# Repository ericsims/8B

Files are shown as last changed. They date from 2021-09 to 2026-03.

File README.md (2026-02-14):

# 8 Bit TTL Computer
a simple 8 bit CISC computer built using TTL logic

## SW DEV

### packages
`sudo apt-get install python3-tk ffmpeg`

### customasm
`curl --proto '=https' --tlsv1.3 https://sh.rustup.rs -sSf | sh`
`cargo install customasm`

### python setup

`python3 -m venv .venv`
`source .venv/bin/activate`
`python -m pip install pip-tools`
`pip-compile.exe requirements.in`
`pip install -r requirements.txt`

## CPLD DEV

### Quartus

Quartus II v13.0 sp1
https://www.intel.com/content/www/us/en/software-kit/711791/intel-quartus-ii-web-edition-design-software-version-13-0sp1-for-windows.html

### POF2JED

https://www.microchip.com/en-us/products/fpgas-and-plds/spld-cplds/pld-design-resources

### GHDL

in MSYS2 MSYS `pacman -S mingw64/mingw-w64-x86_64-ghdl-llvm`

### gtkwave

`https://github.com/gtkwave/gtkwave/releases`

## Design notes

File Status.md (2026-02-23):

# Backplane

DONE

# ALU Ctrl

DONE

# ALU Logic

DONE

# ALU Adder

DONE

# Memory Proto

DONE

# Registers

- [x] board keep out
- [x] silkscreen
- [x] part number/date
- [x] teardrops
- [x] polygons
- [x] run out jobs
- [x] quote
- [ ] order
- [ ] assemble

# Scratch

- [x] board keep out
- [x] silkscreen
- [x] part number/date
- [x] teardrops
- [x] polygons
- [x] run out jobs
- [x] quote
- [ ] order
- [ ] assemble

# Program Counter

- [x] board keep out
- [x] silkscreen
- [x] part number/date
- [x] teardrops
- [x] polygons
- [x] run out jobs
- [x] quote
- [ ] order
- [ ] assemble

# SRAM

- [x] board keep out
- [x] silkscreen
- [x] part number/date
- [x] teardrops
- [x] polygons
- [ ] run out jobs
- [ ] quote
- [ ] order
- [ ] assemble

# EEPROM

- [x] board keep out
- [x] silkscreen
- [x] part number/date
- [x] teardrops
- [x] polygons
- [ ] run out jobs
- [ ] quote
- [ ] order
- [ ] assemble

# Clock Proto

- [ ] board keep out
- [ ] silkscreen
- [ ] part number/date
- [ ] teardrops
- [ ] polygons
- [ ] run out jobs
- [ ] quote
- [ ] order
- [ ] assemble

# Memory Address Decoder

- [x] board keep out
- [x] silkscreen
- [x] part number/date
- [x] teardrops
- [x] polygons
- [ ] run out jobs
- [ ] quote
- [ ] order
- [ ] assemble

# Remaining Work
- Power Module - 8 hours
- Control Module - 24 hours
- Memory Address Register - 8 hours
- Memory Decoder - DONE, NEED QUOTE
- EEPROM - DONE, NEED QUOTE
- SD card - 8 hours
- Ethernet - 12 hours
- Graphics - 12 hours
- UART - 12 hours
- Extended RAM - 8 hours
- Keyboard - 12 hours
- SNES - 4 hours?

pcb assembly: 40 hours
total pcb design work: 160 hours

mechanical design: ~40?
mechanical assembly 12 hours?

total mech work: 52 hours

hardware debug effort???
control debugging: 80 hours

app dev
graphics demos: 40 hours
ethernet demos: 40 hours
weather app: 80 hours
snakey game: 80 hours?
total app dev: 240

display prep
16 hours

total: 556 hours

All PCBs/Hardware ordered by 3/7

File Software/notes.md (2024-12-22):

# instructions

consider adding a set of jump instructions that is relative to PC, rather than just an immediate address. This would allow for programs to be dynamically ran out of ram, or even the stack.

Need to finish test coverage of all the instructions and corner cases

# math

finish corner case testing of existing math functions

sine CORDIC needs more testing. I am not sure it is always converging correctly. Consider caching the sine/cosine outputs in the future if desired - or maybe just return both always?

sqrt and ln are broken due to some change in the offset addressing. consider ditching the LUT approach and just write a hyperbolic CORDIC implementation.

# file system

consider a FAT16 FS implementation on SD card. This would be simple on SPI bus. James has a video on it.

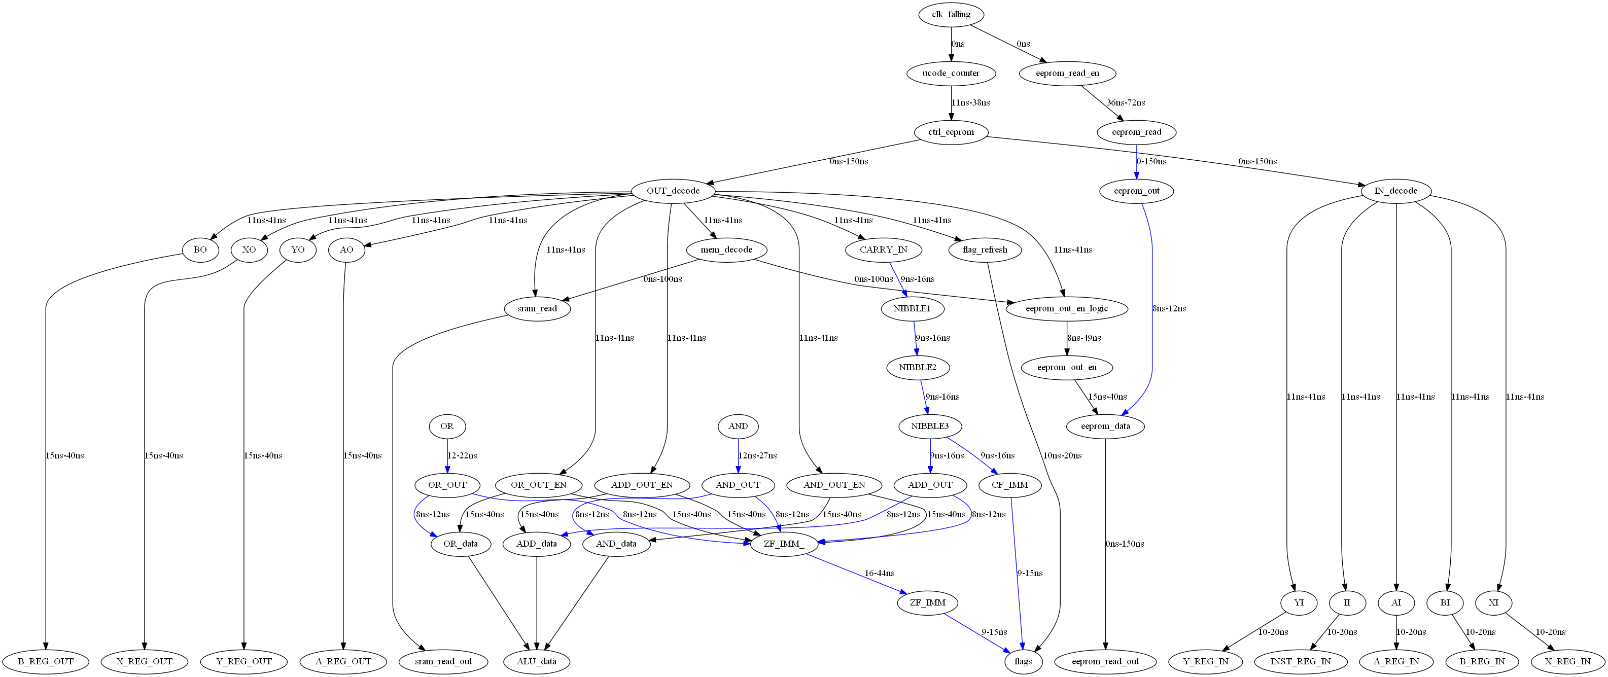
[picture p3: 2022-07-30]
Software/lib_dev/Timing/output.png

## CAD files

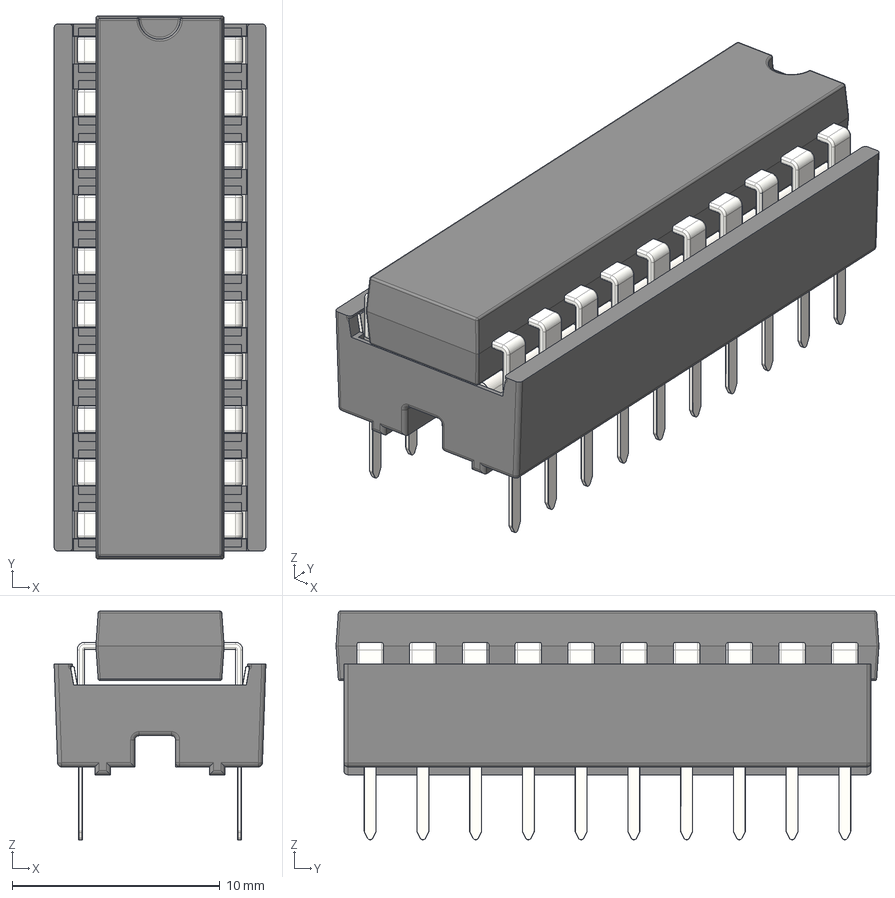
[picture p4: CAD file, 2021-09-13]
Hardware/ic-dip-packages-with-sockets-in-pitch-7-62mm-1.snapshot.2/DIP-20 W7.62mm IC with Socket.stp
10.2 x 26.1 x 11.0 mm
Stamped Dual Wipe Contact for DIP Sockets x 20
Body DIP-20 P7.62mm Socket
IC Beinchen x 20
DIP-20 W7.62

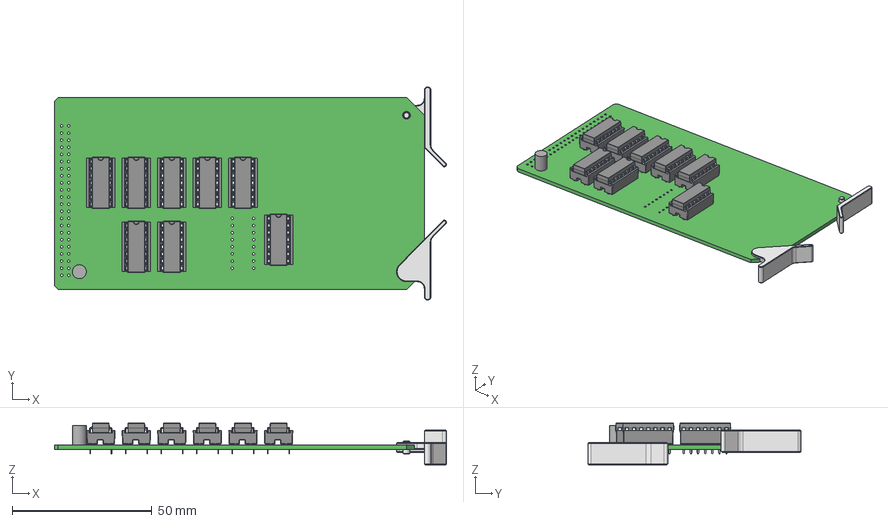
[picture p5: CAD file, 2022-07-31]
Hardware/Memory Address Decoder/Mechanical/Memory Address Decoder.step
140.0 x 76.2 x 14.9 mm
Stamped_Dual_Wipe_Contact_for_DIP_Sockets x 112
Body_DIP-14_P7.62mm_Socket x 8
IC_Beinchen x 112
DIP-14_W7.62 x 8
Ejector x 2

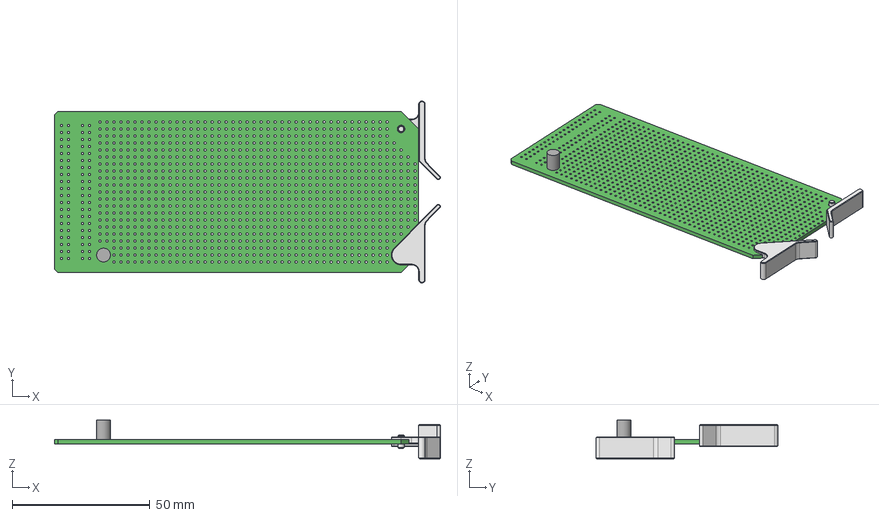
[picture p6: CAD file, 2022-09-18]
Hardware/Memory_Proto/Mechanical/Memory_Proto.step
140.0 x 66.0 x 14.0 mm
Ejector x 2

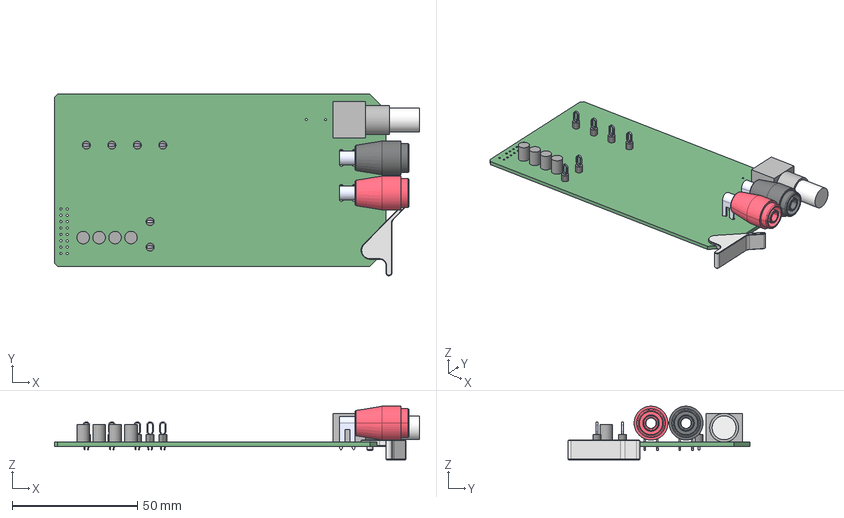
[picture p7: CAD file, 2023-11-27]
Hardware/Power_Clock_proto/Mechanical/Power_Clock_proto.step
145.4 x 72.4 x 21.4 mm
keystone-PN5011 x 6
Extruded
CT3151SP-0
CT3151SP-2
Ejector

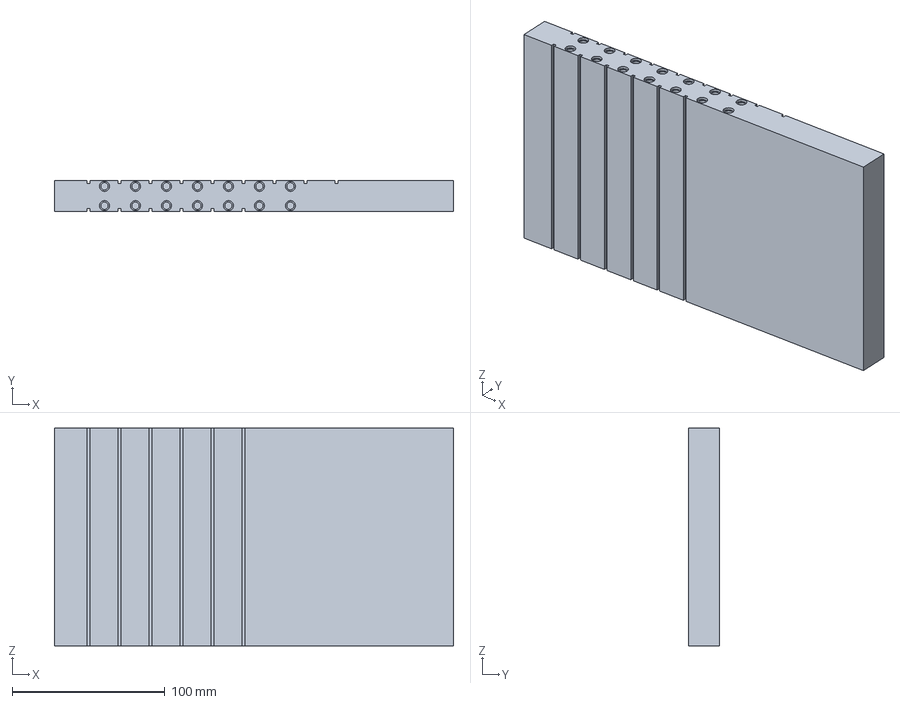
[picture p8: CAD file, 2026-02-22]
Mechanical/card_cage/mid_cage_b.FCStd
261.6 x 20.3 x 142.7 mm

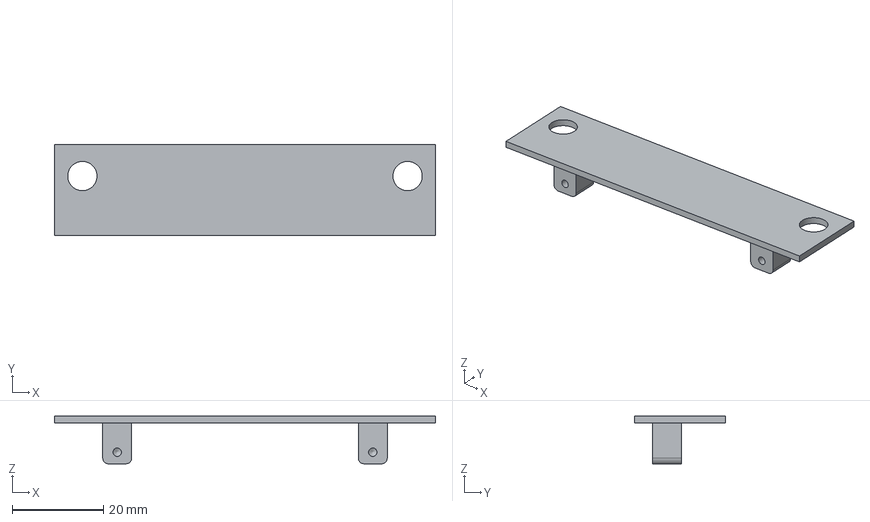
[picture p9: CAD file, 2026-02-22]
Mechanical/export/Reg_Cover_Plain.step
83.3 x 19.8 x 10.4 mm

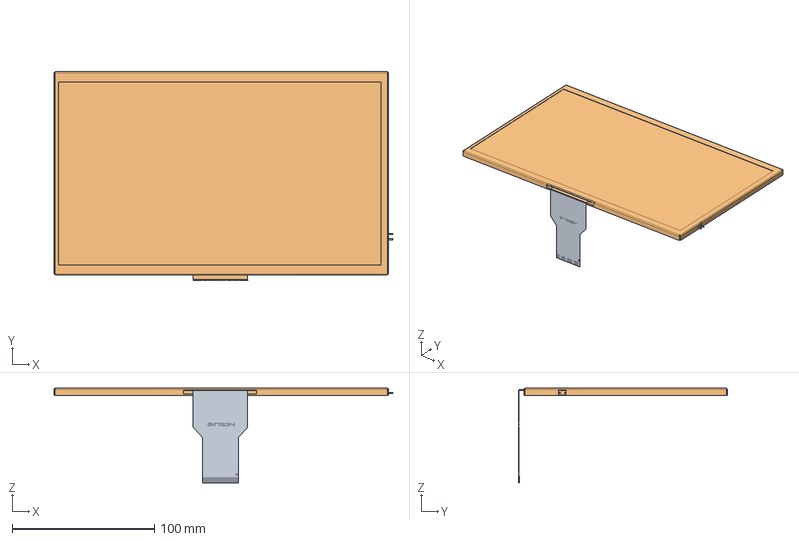
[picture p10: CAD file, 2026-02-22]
Mechanical/front/ER-TFT101-1_screen.FCStd
238.2 x 146.7 x 66.4 mm
Slice.002

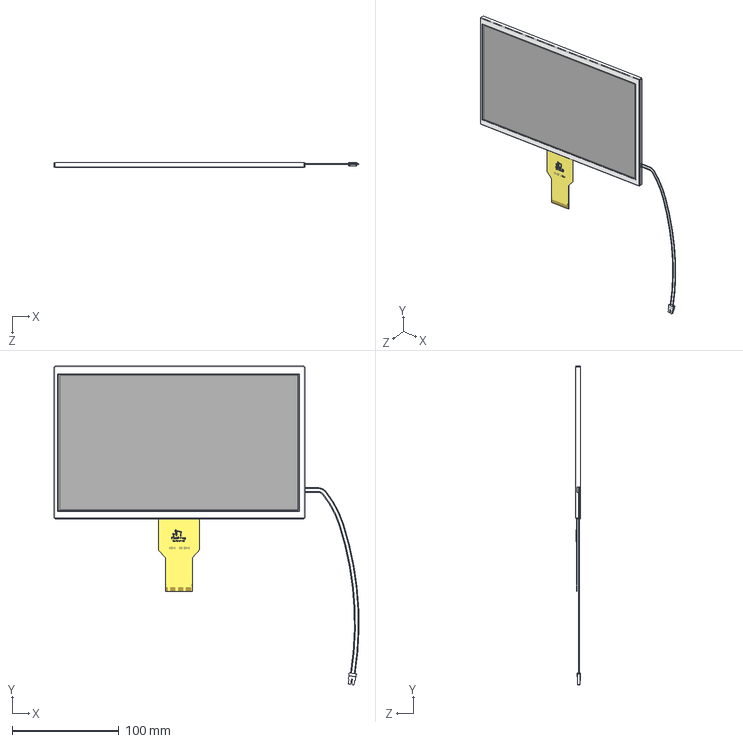
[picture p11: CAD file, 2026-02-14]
Mechanical/vendor_models/ER-TFT101B-4-1.STEP
285.5 x 298.5 x 5.00 mm
10.1 DISPLAY BEZEL
Backlight Connector

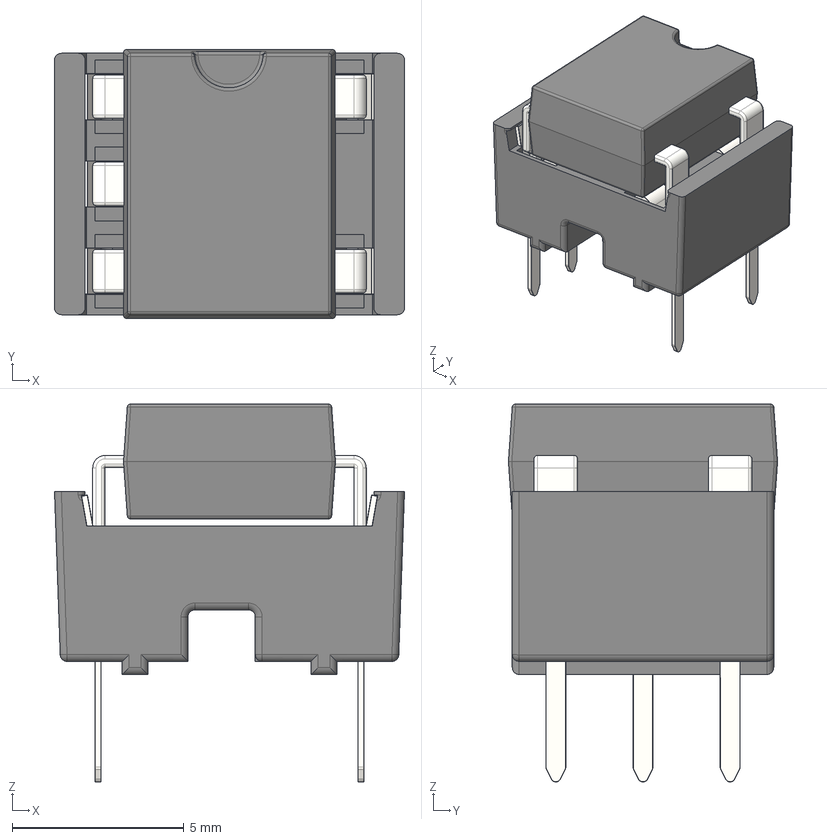
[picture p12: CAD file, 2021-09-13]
Hardware/ic-dip-packages-with-sockets-in-pitch-7-62mm-1.snapshot.2/DIP-5 W7.62mm IC with Socket.stp
10.2 x 7.85 x 11.0 mm
Stamped Dual Wipe Contact for DIP Sockets x 5
IC Beinchen x 5
DIP-5 W7.62
Body DIP-5 P7.62mm Socket

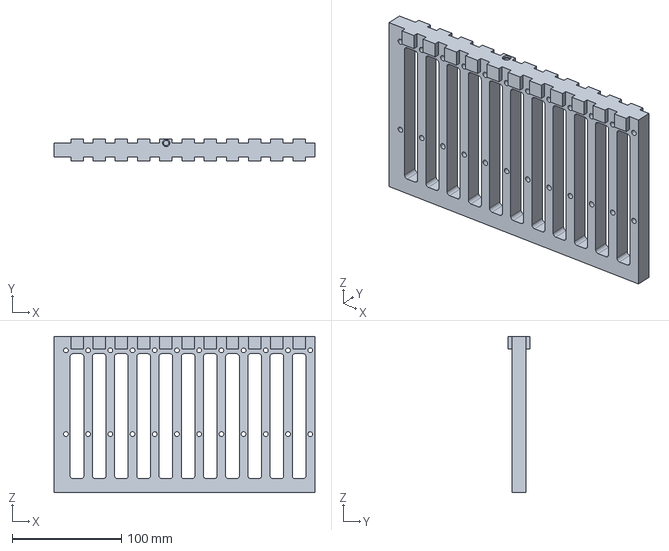
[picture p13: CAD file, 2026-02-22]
Mechanical/card_cage/mid_cage.FCStd
238.8 x 20.3 x 142.7 mm

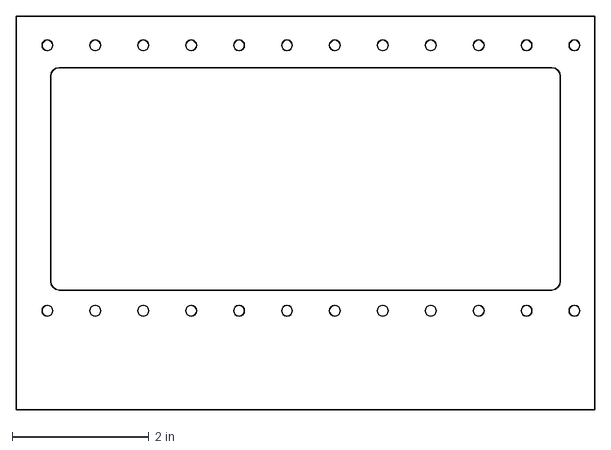
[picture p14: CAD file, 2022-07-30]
Mechanical/centerwall.dxf
8.45 x 5.75 in

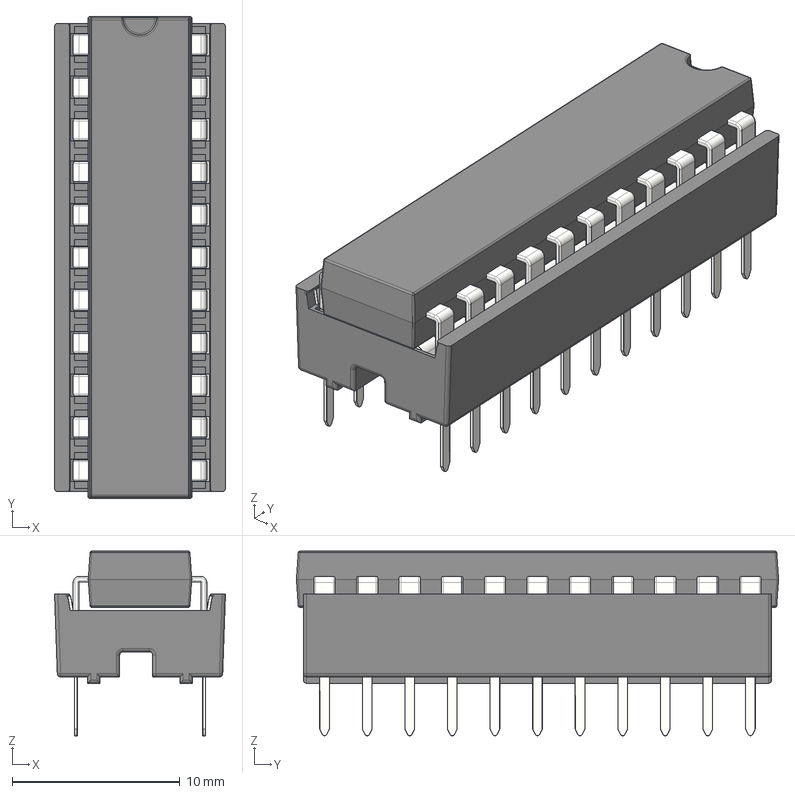
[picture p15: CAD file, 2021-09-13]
Hardware/ic-dip-packages-with-sockets-in-pitch-7-62mm-1.snapshot.2/DIP-22 W7.62mm IC with Socket.stp
10.2 x 28.8 x 11.0 mm
Stamped Dual Wipe Contact for DIP Sockets x 22
Body DIP-22 P7.62mm Socket
IC Beinchen x 22
DIP-22 W7.62

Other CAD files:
Mechanical/Assembly.FCStd
Mechanical/pcbs/ALU_Ctrl_Assembly.FCStd
Mechanical/front/Front Assembly.FCStd
Hardware/Backplane/Mechanical/Backplane.step
Mechanical/pcbs/Reg_Cover_Blank.FCStd
Mechanical/card_cage/card_cage.FCStd
Hardware/ALU_Add_Shift/Mechanical/6403217136.iam
Hardware/ALU_Add_Shift/Mechanical/6403219456.iam
Hardware/ALU_Add_Shift/Mechanical/6403219696.iam
Hardware/ALU_Add_Shift/Mechanical/6517111024.iam
Hardware/ALU_Add_Shift/Mechanical/ALU_Add_Shift.iam
Hardware/ALU_Add_Shift/Mechanical/Board.iam
Hardware/ALU_Add_Shift/Mechanical/Body_DIP-14_P7.62mm_Socket.ipt
Hardware/ALU_Add_Shift/Mechanical/Body_DIP-16_P7.62mm_Socket.ipt
Hardware/ALU_Add_Shift/Mechanical/Body_DIP-20_P7.62mm_Socket.ipt
Hardware/ALU_Add_Shift/Mechanical/C1.iam
Hardware/ALU_Add_Shift/Mechanical/C13.iam
Hardware/ALU_Add_Shift/Mechanical/C14.iam
Hardware/ALU_Add_Shift/Mechanical/C15.iam
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

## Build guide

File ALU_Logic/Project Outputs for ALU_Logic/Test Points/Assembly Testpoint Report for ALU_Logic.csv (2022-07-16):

Net | Name | X Coord | Y Coord | Side | Hole Size | Type
M\10 | TP8-1 | 4900mil | 2700mil | Top | 62.992mil | Through hole
M\9 | TP7-1 | 4400mil | 2700mil | Top | 62.992mil | Through hole
M\8 | TP6-1 | 5400mil | 2700mil | Top | 62.992mil | Through hole
M\5 | TP5-1 | 3600mil | 1500mil | Top | 62.992mil | Through hole
M\4 | TP4-1 | 2600mil | 1500mil | Top | 62.992mil | Through hole
AND_OUT# | TP3-1 | 1600mil | 1500mil | Top | 62.992mil | Through hole
VCC | TP2-1 | 2100mil | 1200mil | Top | 62.992mil | Through hole
GND | TP1-1 | 2400mil | 1200mil | Top | 62.992mil | Through hole

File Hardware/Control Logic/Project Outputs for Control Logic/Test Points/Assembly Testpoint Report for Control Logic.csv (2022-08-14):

Net | Name | X Coord | Y Coord | Side | Hole Size | Type
GND | TP11-1 | 11000mil | 1200mil | Top | 62.992mil | Through hole
GND | TP12-1 | 10700mil | 1200mil | Top | 62.992mil | Through hole
VCC | TP14-1 | 10100mil | 1200mil | Top | 62.992mil | Through hole
GND | TP13-1 | 10400mil | 1200mil | Top | 62.992mil | Through hole
GND | TP9-1 | 11600mil | 1200mil | Top | 62.992mil | Through hole
GND | TP10-1 | 11300mil | 1200mil | Top | 62.992mil | Through hole
GND | TP8-1 | 11900mil | 1200mil | Top | 62.992mil | Through hole
DBG | TP7-1 | 12200mil | 1200mil | Top | 62.992mil | Through hole
AT# | TP6-1 | 12500mil | 1200mil | Top | 62.992mil | Through hole
HT# | TP5-1 | 12800mil | 1200mil | Top | 62.992mil | Through hole
RST# | TP4-1 | 13100mil | 1200mil | Top | 62.992mil | Through hole
LM# | TP3-1 | 13400mil | 1200mil | Top | 62.992mil | Through hole
RU# | TP1-1 | 3600mil | 7700mil | Bottom | 62.992mil | Through hole
CLK | TP2-1 | 3400mil | 8100mil | Bottom | 62.992mil | Through hole

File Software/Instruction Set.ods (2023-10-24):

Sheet: Sheet1_2
LAI | Load A Immediate | 0x02 | LAI, VAL
0 | FETCH
1 | FETCH
2 | FETCH
3 | MC, CE
4 | MO, AI, RU
LBI | Load B Immediate | 0x03 | LBI, VAL
0 | FETCH
1 | FETCH
2 | FETCH
3 | MC, CE
4 | MO, BI, RU
ADD | A + B → A | 0x04 | ADD
0 | FETCH
1 | FETCH
2 | FETCH
3 | Mn=1, AI, RU, FI
SUB | A + B → A | 0x06 | SUB
0 | FETCH
1 | FETCH
2 | FETCH
3 | Mn=2, AI, RU, FI
JMZ | Jump if zero | 0x07 | JMZ, MSB, LSB
0 | FETCH
1 | FETCH
2 | FETCH
3 | if(ZF, [MC], [CE])
4 | if(ZF, [PI, LN=1 ,MO], [CE, RU])
5 | if(ZF, [MC], [])
6 | if(ZF, [PI, Ln=0, MO, RU], [])
JNZ | Jump if not zero | 0x08 | JNZ, MSB, LSB
0 | FETCH
1 | FETCH
2 | FETCH
3 | if(ZF, [CE], [MC])
4 | if(ZF, [CE, RU], [PI, LN=1 ,MO])
5 | if(ZF, [], [MC])
6 | if(ZF, [], [PI, Ln=0, MO, RU])
STA | Store A to memory | 0x09 | STA, MSB, LSB
0 | FETCH
1 | FETCH
2 | FETCH
3 | MC, CE
4 | MO, PH
5 | MC, CE
6 | MO, PH
7 | PP, MA, Ln=0
8 | PP, MA, Ln=1
9 | AO, MI, RU
LBA | A → B | 0x0A | LBA
0 | FETCH
1 | FETCH
2 | FETCH
3 | BI, AO, RU
LDA | load memory to A | 0x0B | LDA, MSB, LSB
0 | FETCH
1 | FETCH
2 | FETCH
3 | MC , CE
4 | MO, PH
5 | MC, CE
6 | MO, PH
7 | PP, MA, Ln=0
8 | PP, MA, Ln=1
9 | AI, MO, RU
LDB | load memory to B | 0x0C | LDB, MSB, LSB
0 | FETCH
1 | FETCH
2 | FETCH
3 | MC , CE
4 | MO, PH
5 | MC, CE
6 | MO, PH
7 | PP, MA, Ln=0
8 | PP, MA, Ln=1
9 | BI, MO, RU
JMC | Jump if carry | 0x0D | JMC, MSB, LSB
0 | FETCH
1 | FETCH
2 | FETCH
3 | if(CF, [MC], [CE])
4 | if(CF, [PI, LN=1 ,MO], [CE, RU])
5 | if(CF, [MC], [])
6 | if(CF, [PI, Ln=0, MO, RU], [])
JNC | Jump if not carry | 0x0E | JNC, MSB, LSB
0 | FETCH
1 | FETCH
2 | FETCH
3 | if(CF, [CE], [MC])
4 | if(CF, [CE, RU], [PI, LN=1 ,MO])
5 | if(CF, [], [MC])
6 | if(CF, [], [PI, Ln=0, MO, RU])
STI | Store Immediate to memory | 0x0F | STI, VAL, MSB, LSB
0 | FETCH
1 | FETCH
2 | FETCH
3 | MC , CE
4 | MO, PH
5 | MC, CE
6 | MO, PH
7 | MC, CE
8 | MO, PH
9 | PP, MA, Ln=0
10 | PP, MA, Ln=1
11 | PP, MI, RU
CAL | Call subroutine | 0X10 | CAL, MSB, LSB
0 | FETCH
1 | FETCH
2 | FETCH
3 | CE
4 | CE
5 | PH, PO, Ln=1
6 | PH, PO, Ln=0, MC
7 | PI, LN=1 ,MO
8 | MC, CE
9 | PI, Ln=0, MO, RU
RET | Return from subroutine | 0x11 | RET
0 | FETCH
1 | FETCH
2 | FETCH
3 | PP, MA, Ln=0
4 | PP, MA, Ln=1, RU
JMN | Jump if negative | 0x12 | JMN, MSB, LSB
0 | FETCH
1 | FETCH
2 | FETCH
3 | if(NF, [MC], [CE])
4 | if(NF, [PI, LN=1 ,MO], [CE, RU])
5 | if(NF, [MC], [])
6 | if(NF, [PI, Ln=0, MO, RU], [])
RLC | shift left | 0x13 | RLC
0 | FETCH
1 | FETCH
2 | FETCH
3 | Mn=6, AI, RU, FI
RRC | right shift | 0x14 | RLC
0 | FETCH
1 | FETCH
2 | FETCH
3 | Mn=7, AI, RU, FI
PHA | push a to stack | 0x15 | PHA
0 | FETCH
1 | FETCH
2 | FETCH
3 | AO, PH, RU
SSA | Store A to MI at address on stack | 0x17 | SSA
0 | FETCH
1 | FETCH
2 | FETCH
3 | PP, MA, Ln=1
4 | PP, MA, Ln=0
5 | MI, AO, RU
LSA | Load memory at address in stack to A | 0x18 | LSA
0 | FETCH
1 | FETCH
2 | FETCH
3 | PP, MA, Ln=1
4 | PP, MA, Ln=0
5 | MO, AI, RU
TTA | Test instruction. Asserts that A reg equals operand | 0xFE | TTA, VAL
0 | FETCH
1 | FETCH
2 | FETCH
4 | MC, CE
5 | RU, (sim to check that A == operand)
TTZ | Test instruction. Asserts that ZF reg equals operand | 0xFD | TTZ, VAL
0 | FETCH
1 | FETCH
2 | FETCH
4 | MC, CE
5 | RU, (sim to check that ZF == operand)
TTC | Test instruction. Asserts that CF equals operand | 0xFC | TTC, VAL
0 | FETCH
1 | FETCH
2 | FETCH
4 | MC, CE
5 | RU, (sim to check that CF == operand)
TTN | Test instruction. Asserts that NF equals operand | 0xFB | TTN, VAL
0 | FETCH
1 | FETCH
2 | FETCH
4 | MC, CE
5 | RU, (sim to check that NF == operand)
AND | A & B → A | 0x19 | AND
0 | FETCH
1 | FETCH
2 | FETCH
3 | Mn=3, AI, RU, FI
OOR | A | B → A | 0x20 | OOR
0 | FETCH
1 | FETCH
2 | FETCH
3 | Mn=4, AI, RU, FI
XOR | A XOR B → A | 0x21 | XOR
0 | FETCH
1 | FETCH
2 | FETCH
3 | Mn=5, AI, RU, FI

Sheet: Sheet1
LAI | Load A Immediate | 0x02 | LAI, VAL
0 | FETCH
1 | FETCH
2 | FETCH
3 | MC, CE
4 | MO, AI, RU
HLT |  | 0xFF | HLT
0 | FETCH
1 | FETCH
2 | FETCH
3 | HLT
LBI | Load B Immediate | 0x03 | LBI, VAL
0 | FETCH
1 | FETCH
2 | FETCH
3 | MC, CE
4 | MO, BI, RU
ADD | A + B → A | 0x04 | ADD
0 | FETCH
1 | FETCH
2 | FETCH
3 | Mn=1, AI, RU, FI
JMP | Jump to address | 0x05 | JMP, MSB, LSB
0 | FETCH
1 | FETCH
2 | FETCH
3 | MC
4 | PI, LN=1 ,MO
5 | MC
6 | PI, Ln=0, MO, RU
SUB | A + B → A | 0x06 | SUB
0 | FETCH
1 | FETCH
2 | FETCH
3 | Mn=2, AI, RU, FI
JMZ | Jump if zero | 0x07 | JMZ, MSB, LSB
0 | FETCH
1 | FETCH
2 | FETCH
3 | if(ZF, [MC], [CE])
4 | if(ZF, [PI, LN=1 ,MO], [CE, RU])
5 | if(ZF, [MC], [])
6 | if(ZF, [PI, Ln=0, MO, RU], [])
JNZ | Jump if not zero | 0x08 | JNZ, MSB, LSB
0 | FETCH
1 | FETCH
2 | FETCH
3 | if(ZF, [CE], [MC])
4 | if(ZF, [CE, RU], [PI, LN=1 ,MO])
5 | if(ZF, [], [MC])
6 | if(ZF, [], [PI, Ln=0, MO, RU])
STA | Store A to memory | 0x09 | STA, MSB, LSB
0 | FETCH
1 | FETCH
2 | FETCH
3 | MC, CE
4 | MO, PH
5 | MC, CE
6 | MO, PH
7 | PP, MA, Ln=0
8 | PP, MA, Ln=1
9 | AO, MI, RU
LBA | A → B | 0x0A | LBA
0 | FETCH
1 | FETCH
2 | FETCH
3 | BI, AO, RU
LDA | load memory to A | 0x0B | LDA, MSB, LSB
0 | FETCH
1 | FETCH
2 | FETCH
3 | MC , CE
4 | MO, PH
5 | MC, CE
6 | MO, PH
7 | PP, MA, Ln=0
8 | PP, MA, Ln=1
9 | AI, MO, RU
LDB | load memory to B | 0x0C | LDB, MSB, LSB
0 | FETCH
1 | FETCH
2 | FETCH
3 | MC , CE
4 | MO, PH
5 | MC, CE
6 | MO, PH
7 | PP, MA, Ln=0
8 | PP, MA, Ln=1
9 | BI, MO, RU
JMC | Jump if carry | 0x0D | JMC, MSB, LSB
0 | FETCH
1 | FETCH
2 | FETCH
3 | if(CF, [MC], [CE])
4 | if(CF, [PI, LN=1 ,MO], [CE, RU])
5 | if(CF, [MC], [])
6 | if(CF, [PI, Ln=0, MO, RU], [])
JNC | Jump if not carry | 0x0E | JNC, MSB, LSB
0 | FETCH
1 | FETCH
2 | FETCH
3 | if(CF, [CE], [MC])
4 | if(CF, [CE, RU], [PI, LN=1 ,MO])
5 | if(CF, [], [MC])
6 | if(CF, [], [PI, Ln=0, MO, RU])
STI | Store Immediate to memory | 0x0F | STI, VAL, MSB, LSB
0 | FETCH
1 | FETCH
2 | FETCH
3 | MC , CE
4 | MO, PH
5 | MC, CE
6 | MO, PH
7 | MC, CE
8 | MO, PH
9 | PP, MA, Ln=0
10 | PP, MA, Ln=1
11 | PP, MI, RU
CAL | Call subroutine | 0X10 | CAL, MSB, LSB
0 | FETCH
1 | FETCH
2 | FETCH
3 | CE
4 | CE
5 | PH, PO, Ln=1
6 | PH, PO, Ln=0, MC
7 | PI, LN=1 ,MO
8 | MC, CE
9 | PI, Ln=0, MO, RU
RET | Return from subroutine | 0x11 | RET
0 | FETCH
1 | FETCH
2 | FETCH
3 | PP, MA, Ln=0
4 | PP, MA, Ln=1, RU
JMN | Jump if negative | 0x12 | JMN, MSB, LSB
0 | FETCH
1 | FETCH
2 | FETCH
3 | if(NF, [MC], [CE])
4 | if(NF, [PI, LN=1 ,MO], [CE, RU])
5 | if(NF, [MC], [])
6 | if(NF, [PI, Ln=0, MO, RU], [])
RLC | shift left | 0x13 | RLC
0 | FETCH
1 | FETCH
2 | FETCH
3 | Mn=6, AI, RU, FI
RRC | right shift | 0x14 | RLC
0 | FETCH
1 | FETCH
2 | FETCH
3 | Mn=7, AI, RU, FI
PHA | push a to stack | 0x15 | PHA
0 | FETCH
1 | FETCH
2 | FETCH
3 | AO, PH, RU
SSA | Store A to MI at address on stack | 0x17 | SSA
0 | FETCH
1 | FETCH
2 | FETCH
3 | PP, MA, Ln=1
4 | PP, MA, Ln=0
5 | MI, AO, RU
LSA | Load memory at address in stack to A | 0x18 | LSA
0 | FETCH
1 | FETCH
2 | FETCH
3 | PP, MA, Ln=1
4 | PP, MA, Ln=0
5 | MO, AI, RU
TTA | Test instruction. Asserts that A reg equals operand | 0xFE | TTA, VAL
0 | FETCH
1 | FETCH
2 | FETCH
4 | MC, CE
5 | RU, (sim to check that A == operand)
TTZ | Test instruction. Asserts that ZF reg equals operand | 0xFD | TTZ, VAL
0 | FETCH
1 | FETCH
2 | FETCH
4 | MC, CE
5 | RU, (sim to check that ZF == operand)
TTC | Test instruction. Asserts that CF equals operand | 0xFC | TTC, VAL
0 | FETCH
1 | FETCH
2 | FETCH
4 | MC, CE
5 | RU, (sim to check that CF == operand)
TTN | Test instruction. Asserts that NF equals operand | 0xFB | TTN, VAL
0 | FETCH
1 | FETCH
2 | FETCH
4 | MC, CE
5 | RU, (sim to check that NF == operand)
AND | A & B → A | 0x19 | AND
0 | FETCH
1 | FETCH
2 | FETCH
3 | Mn=3, AI, RU, FI
OOR | A | B → A | 0x20 | OOR
0 | FETCH
1 | FETCH
2 | FETCH
3 | Mn=4, AI, RU, FI
XOR | A XOR B → A | 0x21 | XOR
0 | FETCH
1 | FETCH
2 | FETCH
3 | Mn=5, AI, RU, FI

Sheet: Sheet3
0x00 | nop |  |  |  | total | remaining
0x04 | load a imm | load a dir | load a indir | loadw hl SP | 95 | 33
0x08 | load b imm | load b dir | load b indir | Loadw hl PC
0x0C | loadw hl imm | loadw hl dir | loadw hl indir | load a FR
0x10 | add a b | add a imm | add b imm | load a b
0x14 | addw hl a | addw hl b | addw hl imm | load b a
0x18 | sub a b | sub a imm | sub b imm | loadw SP imm
0x1C | subw hl a | subw hl b | subw hl imm
0x20 | and a b | and a imm | and b imm | andw hl imm |  | written
0x24 | or a b | or a imm | or b imm | orw hl imm |  | tested
0x28 | xor a b | xor a imm | xor b imm | xorw hl imm
0x2C | lshift a | lshift b | rshift a | rishft b
0x30 | store a dir | store a indir | store b dir | store b indir
0x34 | storew HL dir | storew HL indir | store a FR | store imm indir
0x38 | push a | push b | push imm | push dir
0x3C | push indir | store imm dir | storew imm dir | storew imm indir
0x40 | load a (hl) | load b (hl) | store a (hl) | store b (hl)
0x44 | move dir, dir | move dir, indir | move indir, dir | move indir, indir
0x48 | movew dir, dir | movew dir, indir | movew indir, dir | movew indir, indir
0x4C | pushw imm | pushw dir | pushw indir
0x50 | pushw hl | popw hl | pop a | pop b
0x54
0x58
0x5C
0x60
0x64
0x68
0x6C | jmp | jmz | jnz | jmc
0x70 | jnc | jmn | jnn | cal
0x74 | ret
0x78 | assert a | assert b | assert hl | assert CF
0x7C | assert ZF | assert NF |  | hlt

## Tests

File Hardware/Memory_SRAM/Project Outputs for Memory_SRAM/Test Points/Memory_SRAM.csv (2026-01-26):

Net | Name | X Coord | Y Coord | Side | Hole Size | Type
WE# | TP7-1 | 3300mil | 2625mil | Top | 62.992mil | Through hole
CLK | TP1-1 | 2550mil | 2450mil | Top | 62.992mil | Through hole
OUT# | TP3-1 | 2550mil | 2750mil | Top | 62.992mil | Through hole
EN | TP2-1 | 2550mil | 3050mil | Top | 62.992mil | Through hole
LOAD | TP4-1 | 2550mil | 1900mil | Top | 62.992mil | Through hole
VCC | TP5-1 | 3300mil | 3050mil | Top | 62.992mil | Through hole
GND | TP6-1 | 1900mil | 3050mil | Top | 62.992mil | Through hole

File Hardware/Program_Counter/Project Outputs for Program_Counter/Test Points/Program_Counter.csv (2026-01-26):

Net | Name | X Coord | Y Coord | Side | Hole Size | Type
GND | TP1-1 | 4000mil | 3350mil | Top | 62.992mil | Through hole
RST# | TP4-1 | 3400mil | 3350mil | Top | 62.992mil | Through hole
LM# | TP5-1 | 2750mil | 3250mil | Top | 62.992mil | Through hole
CE# | TP8-1 | 1300mil | 2900mil | Top | 62.992mil | Through hole
PO# | TP7-1 | 1300mil | 3100mil | Top | 62.992mil | Through hole
PI# | TP6-1 | 1300mil | 3300mil | Top | 62.992mil | Through hole
CLK | TP3-1 | 4500mil | 2950mil | Top | 62.992mil | Through hole
VCC | TP2-1 | 4500mil | 3200mil | Top | 62.992mil | Through hole
II# | TP9-1 | 4550mil | 1350mil | Top | 62.992mil | Through hole

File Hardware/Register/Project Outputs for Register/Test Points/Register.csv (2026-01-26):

Net | Name | X Coord | Y Coord | Side | Hole Size | Type
HI# | TP13-1 | 1250mil | 2600mil | Top | 62.992mil | Through hole
AO# | TP10-1 | 1250mil | 2750mil | Top | 62.992mil | Through hole
BO# | TP12-1 | 1250mil | 2900mil | Top | 62.992mil | Through hole
HO# | TP14-1 | 1250mil | 3050mil | Top | 62.992mil | Through hole
AI# | TP9-1 | 2850mil | 2500mil | Top | 62.992mil | Through hole
RST# | TP7-1 | 5350mil | 3400mil | Top | 62.992mil | Through hole
BI# | TP11-1 | 2850mil | 1300mil | Top | 62.992mil | Through hole
LM# | TP8-1 | 3200mil | 1300mil | Top | 62.992mil | Through hole
GND | TP4-1 | 5150mil | 1200mil | Top | 62.992mil | Through hole
VCC | TP5-1 | 5225mil | 2300mil | Top | 62.992mil | Through hole
CLK | TP6-1 | 5350mil | 2750mil | Top | 62.992mil | Through hole

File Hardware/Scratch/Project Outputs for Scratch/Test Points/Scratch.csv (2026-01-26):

Net | Name | X Coord | Y Coord | Side | Hole Size | Type
VCC | TP4-1 | 6000mil | 2900mil | Top | 62.992mil | Through hole
KO# | TP11-1 | 3225mil | 1725mil | Top | 62.992mil | Through hole
KI# | TP10-1 | 5700mil | 3000mil | Top | 62.992mil | Through hole
LM# | TP7-1 | 1725mil | 1300mil | Top | 62.992mil | Through hole
GND | TP3-1 | 5700mil | 1200mil | Top | 62.992mil | Through hole
CLK | TP5-1 | 5700mil | 3450mil | Top | 62.992mil | Through hole
RST# | TP6-1 | 5700mil | 3300mil | Top | 62.992mil | Through hole
JI# | TP8-1 | 5700mil | 2850mil | Top | 62.992mil | Through hole
JO# | TP9-1 | 1725mil | 1725mil | Top | 62.992mil | Through hole
DI# | TP12-1 | 5700mil | 3150mil | Top | 62.992mil | Through hole
DO# | TP13-1 | 4725mil | 1725mil | Top | 62.992mil | Through hole

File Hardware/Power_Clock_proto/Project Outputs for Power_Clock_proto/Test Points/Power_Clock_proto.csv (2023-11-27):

Net | Name | X Coord | Y Coord | Side | Hole Size | Type
HT# | TP5-1 | 2300mil | 2900mil | Top | 62.992mil | Through hole
DBG | TP6-1 | 2700mil | 2900mil | Top | 62.992mil | Through hole
RST# | TP4-1 | 1900mil | 2900mil | Top | 62.992mil | Through hole
GND | TP1-1 | 2500mil | 1700mil | Top | 62.992mil | Through hole
VCC | TP2-1 | 2500mil | 1300mil | Top | 62.992mil | Through hole
CLK | TP3-1 | 1500mil | 2900mil | Top | 62.992mil | Through hole

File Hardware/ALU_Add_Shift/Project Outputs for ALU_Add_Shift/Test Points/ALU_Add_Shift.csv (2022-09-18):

Net | Name | X Coord | Y Coord | Side | Hole Size | Type
ADD# | TP3-1 | 4700mil | 2100mil | Top | 62.992mil | Through hole
M\2 | TP4-1 | 4200mil | 2100mil | Top | 62.992mil | Through hole
M\7 | TP6-1 | 5100mil | 2100mil | Top | 62.992mil | Through hole
LEFT# | TP5-1 | 5300mil | 2100mil | Top | 62.992mil | Through hole
CO_SHIFT | TP8-1 | 5200mil | 1800mil | Top | 62.992mil | Through hole
GND | TP1-1 | 5200mil | 1200mil | Top | 62.992mil | Through hole
CO_ADD | TP7-1 | 5400mil | 1300mil | Top | 62.992mil | Through hole
CO_IMM | TP9-1 | 5200mil | 1500mil | Top | 62.992mil | Through hole
VCC | TP2-1 | 5500mil | 3500mil | Top | 62.992mil | Through hole

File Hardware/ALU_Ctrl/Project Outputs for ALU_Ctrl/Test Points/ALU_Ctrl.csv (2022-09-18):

Net | Name | X Coord | Y Coord | Side | Hole Size | Type
GND | TP1-1 | 2000mil | 1300mil | Top | 62.992mil | Through hole
VCC | TP2-1 | 1850mil | 3500mil | Top | 62.992mil | Through hole
LOAD#_X | TP10-1 | 2700mil | 3350mil | Top | 62.992mil | Through hole
LOAD#_Y | TP11-1 | 3300mil | 3400mil | Top | 62.992mil | Through hole
CLK | TP3-1 | 4450mil | 2350mil | Top | 62.992mil | Through hole
RST# | TP4-1 | 3750mil | 1450mil | Top | 62.992mil | Through hole
F4 | TP8-1 | 5100mil | 2850mil | Top | 62.992mil | Through hole
NF | TP7-1 | 5100mil | 2700mil | Top | 62.992mil | Through hole
ZF | TP6-1 | 5100mil | 2550mil | Top | 62.992mil | Through hole
CO | TP5-1 | 5100mil | 2400mil | Top | 62.992mil | Through hole
FI# | TP9-1 | 5100mil | 2250mil | Top | 62.992mil | Through hole

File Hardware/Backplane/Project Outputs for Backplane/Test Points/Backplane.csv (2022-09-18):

Net | Name | X Coord | Y Coord | Side | Hole Size | Type
VCC | TP13-1 | 6800mil | 4600mil | Top | 62.992mil | Through hole
GND | TP8-1 | 6000mil | 4700mil | Top | 62.992mil | Through hole
GND | TP3-1 | 10000mil | 1800mil | Top | 62.992mil | Through hole
VCC | TP9-1 | 10800mil | 1700mil | Top | 62.992mil | Through hole
RST# | TP15-1 | 4600mil | 4900mil | Top | 62.992mil | Through hole
HT# | TP10-1 | 10850mil | 5600mil | Top | 62.992mil | Through hole
AT# | TP11-1 | 10850mil | 5900mil | Top | 62.992mil | Through hole
DBG | TP12-1 | 10850mil | 5300mil | Top | 62.992mil | Through hole
CLK | TP1-1 | 4400mil | 4800mil | Top | 62.992mil | Through hole
LM# | TP2-1 | 3600mil | 5000mil | Top | 62.992mil | Through hole
GND | TP5-1 | 3600mil | 4700mil | Top | 62.992mil | Through hole
GND | TP6-1 | 2800mil | 1800mil | Top | 62.992mil | Through hole
GND | TP7-1 | 6000mil | 1800mil | Top | 62.992mil | Through hole
GND | TP4-1 | 10000mil | 4700mil | Top | 62.992mil | Through hole

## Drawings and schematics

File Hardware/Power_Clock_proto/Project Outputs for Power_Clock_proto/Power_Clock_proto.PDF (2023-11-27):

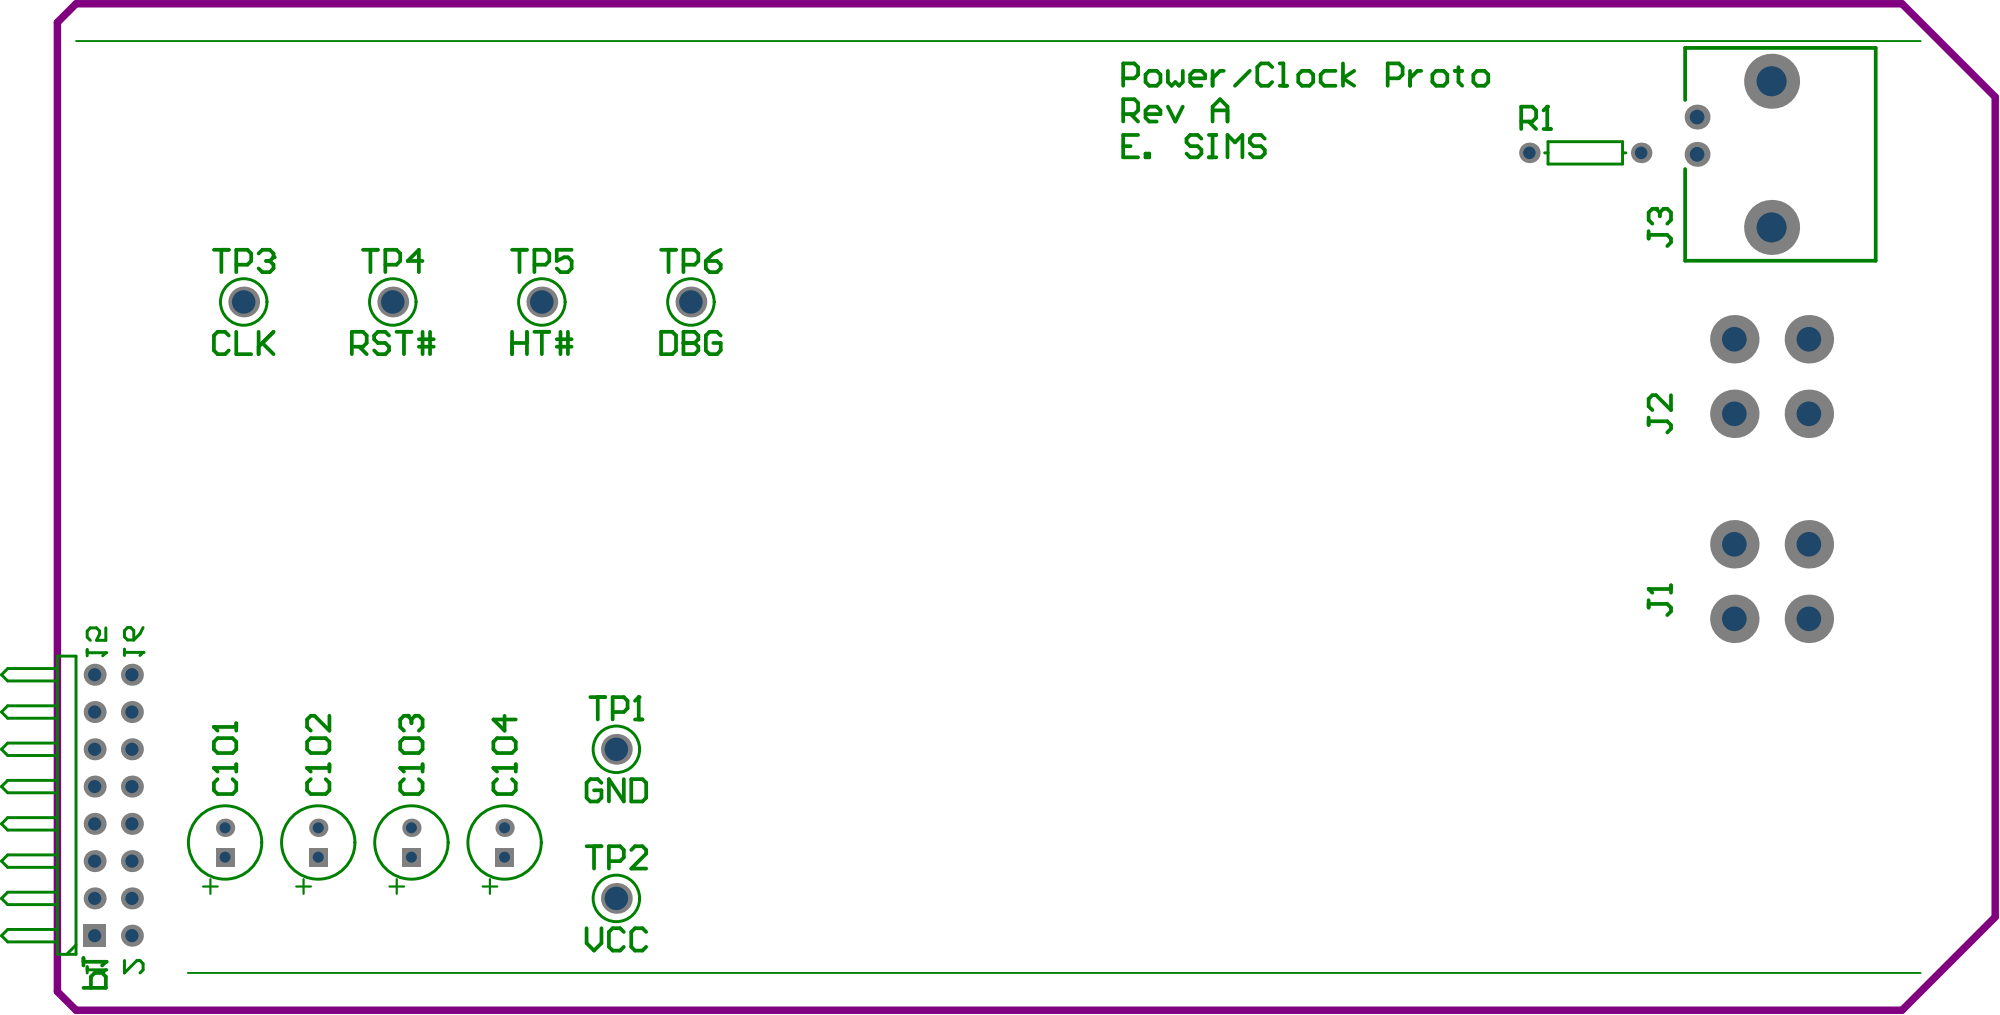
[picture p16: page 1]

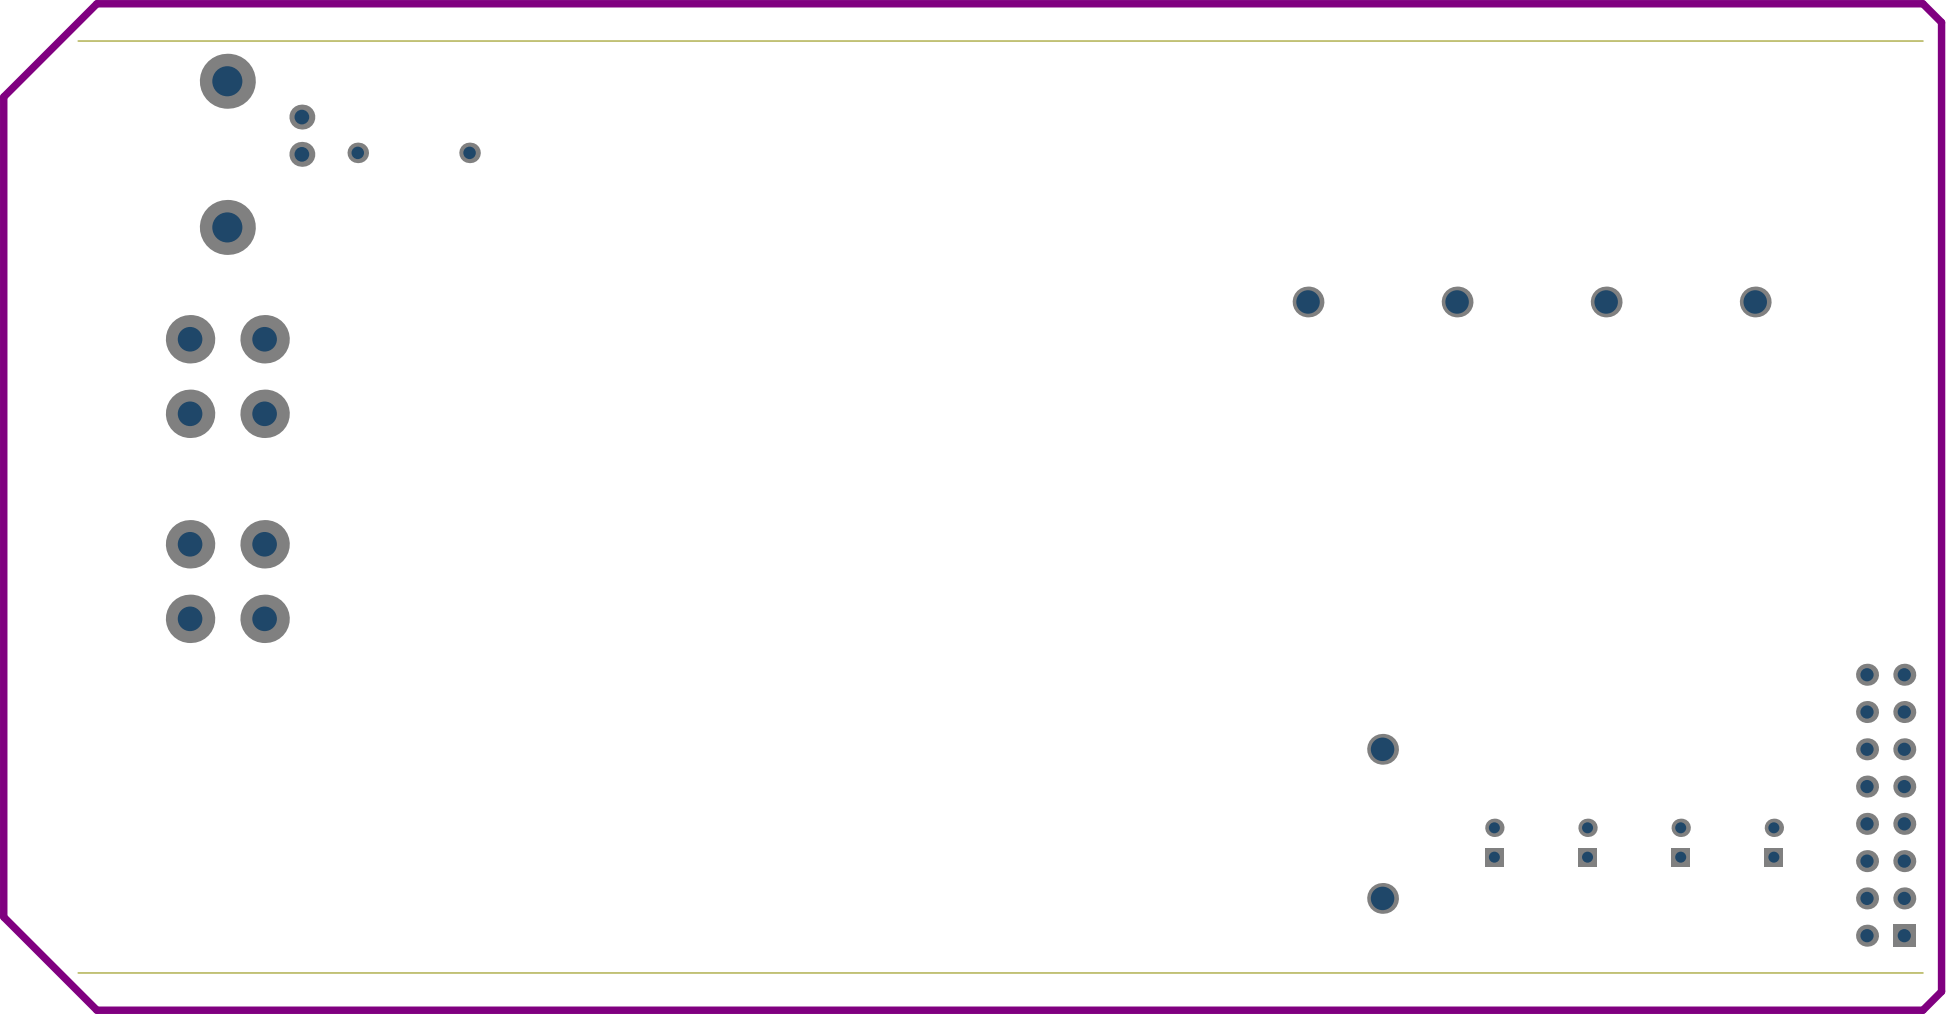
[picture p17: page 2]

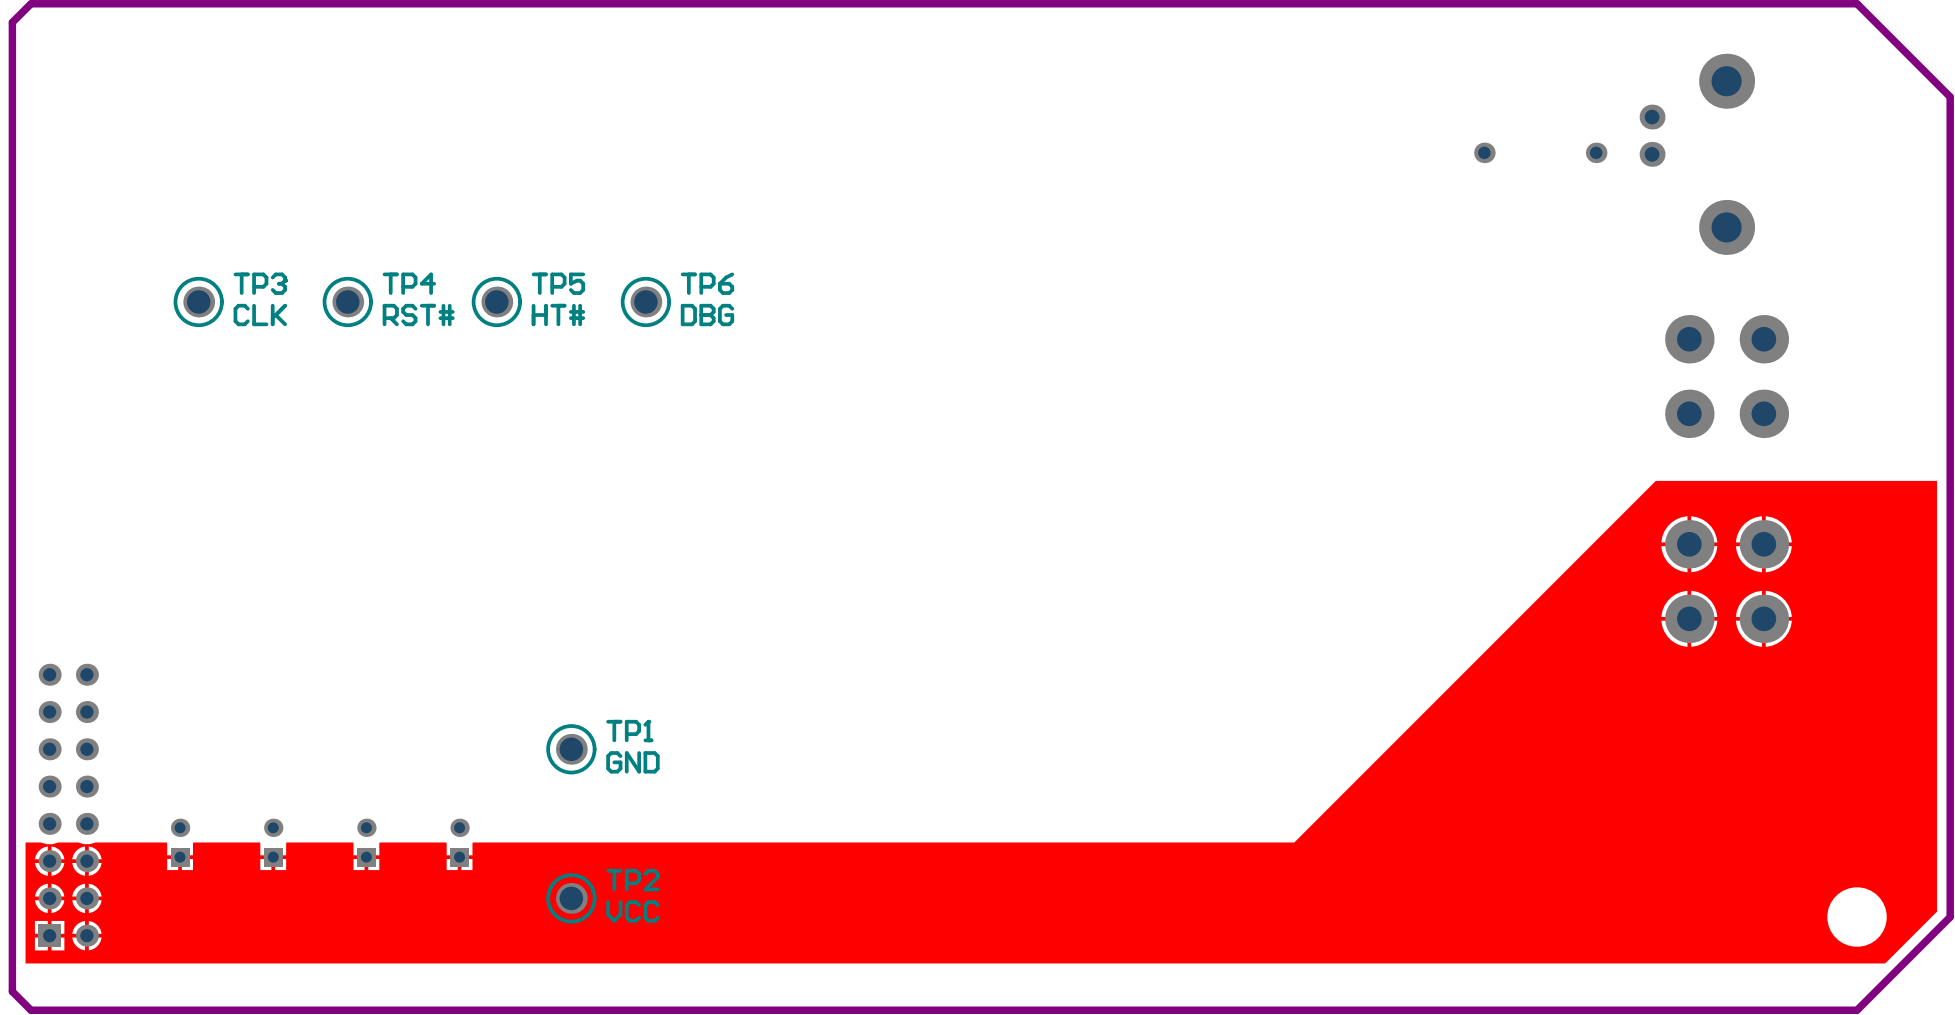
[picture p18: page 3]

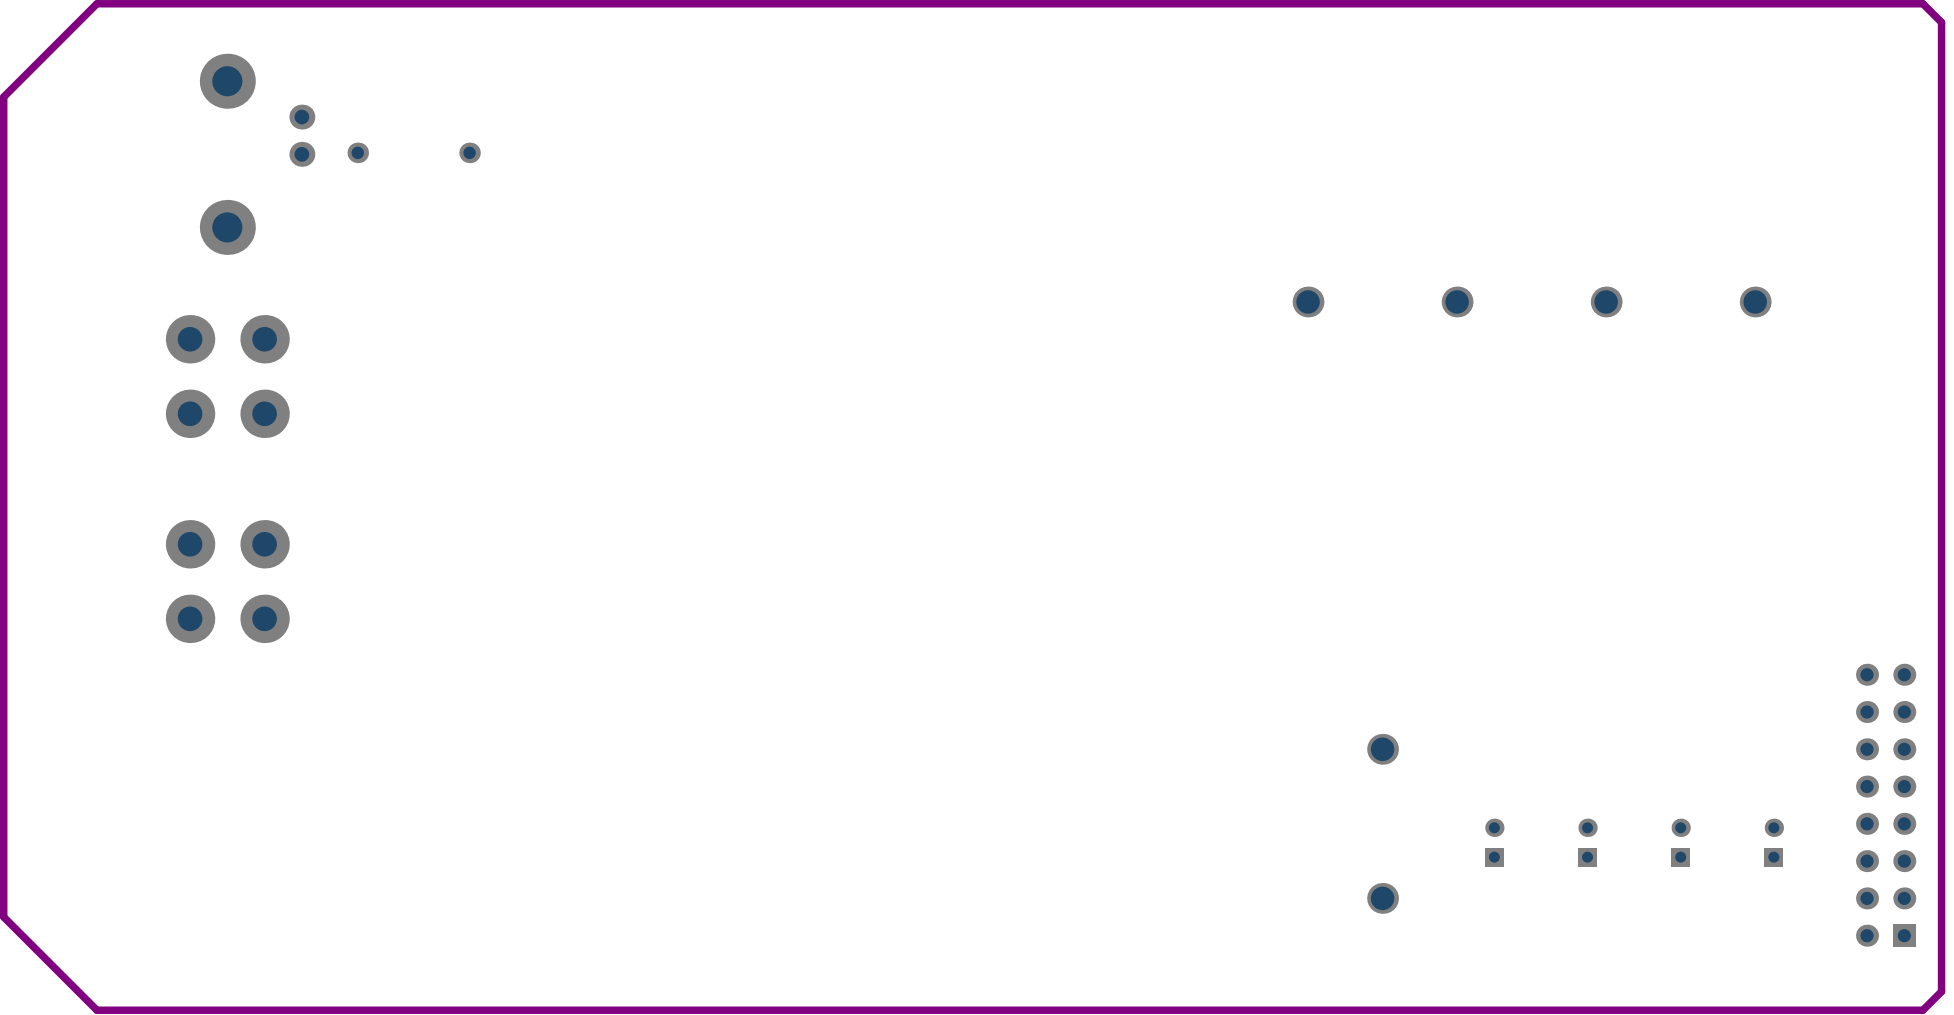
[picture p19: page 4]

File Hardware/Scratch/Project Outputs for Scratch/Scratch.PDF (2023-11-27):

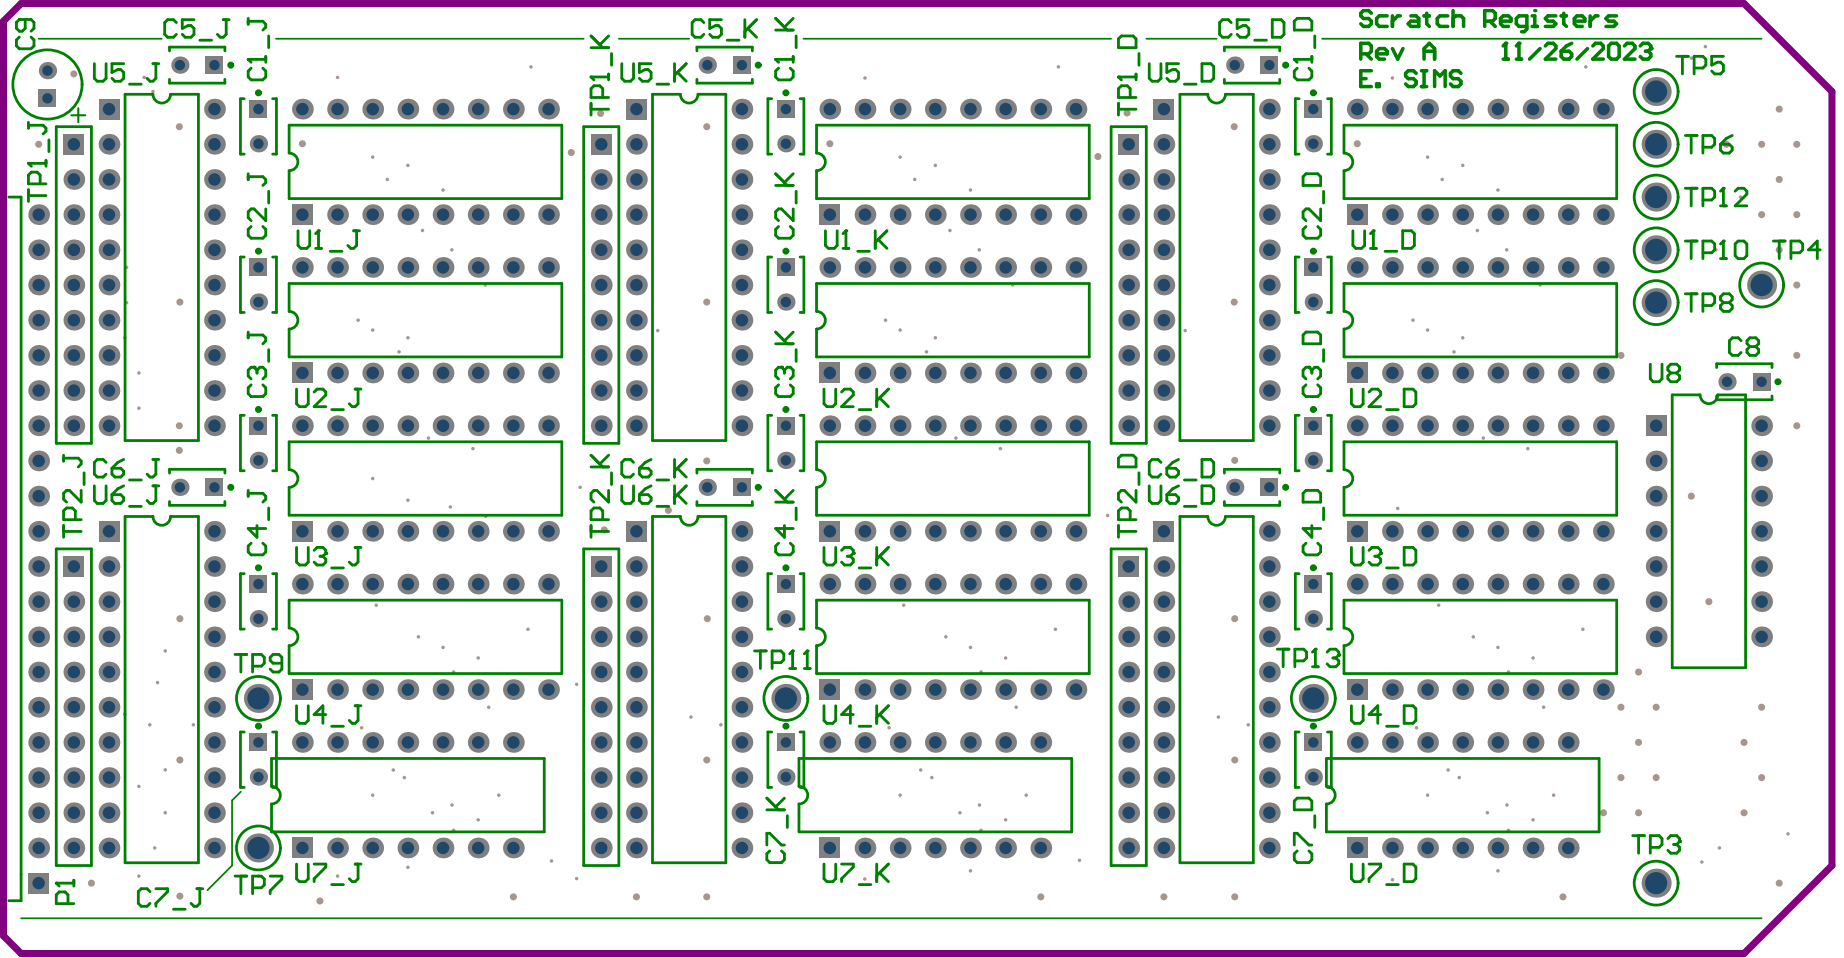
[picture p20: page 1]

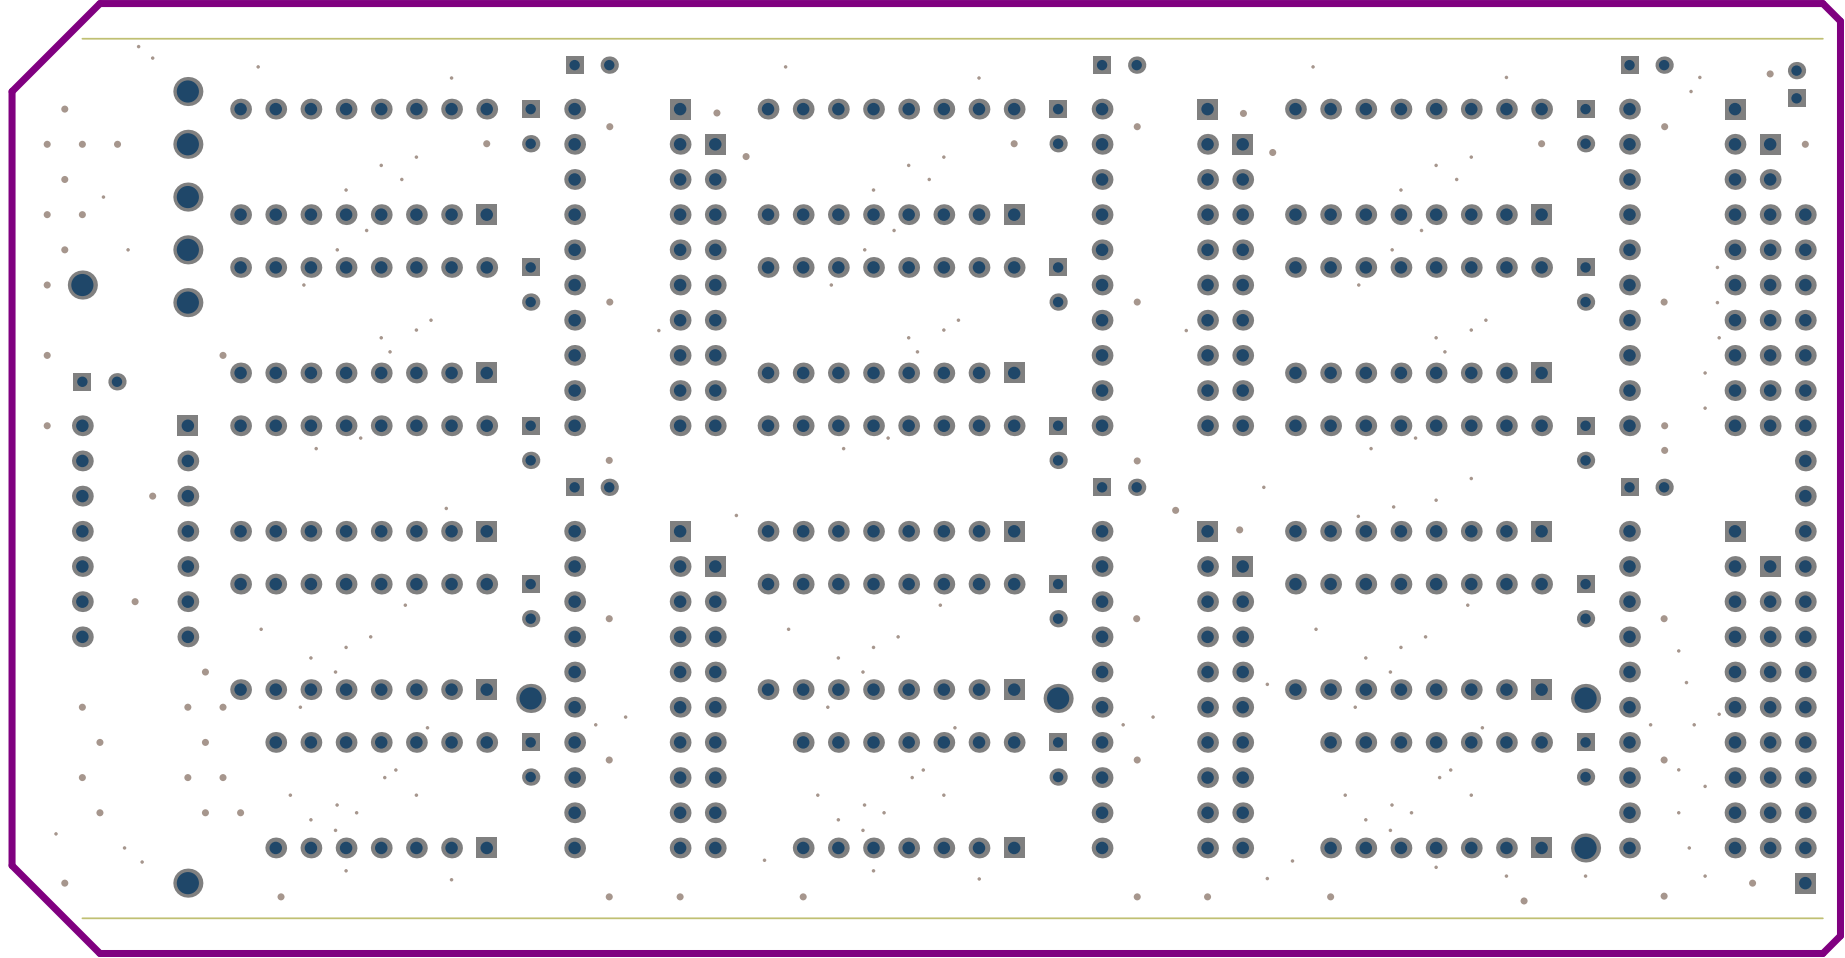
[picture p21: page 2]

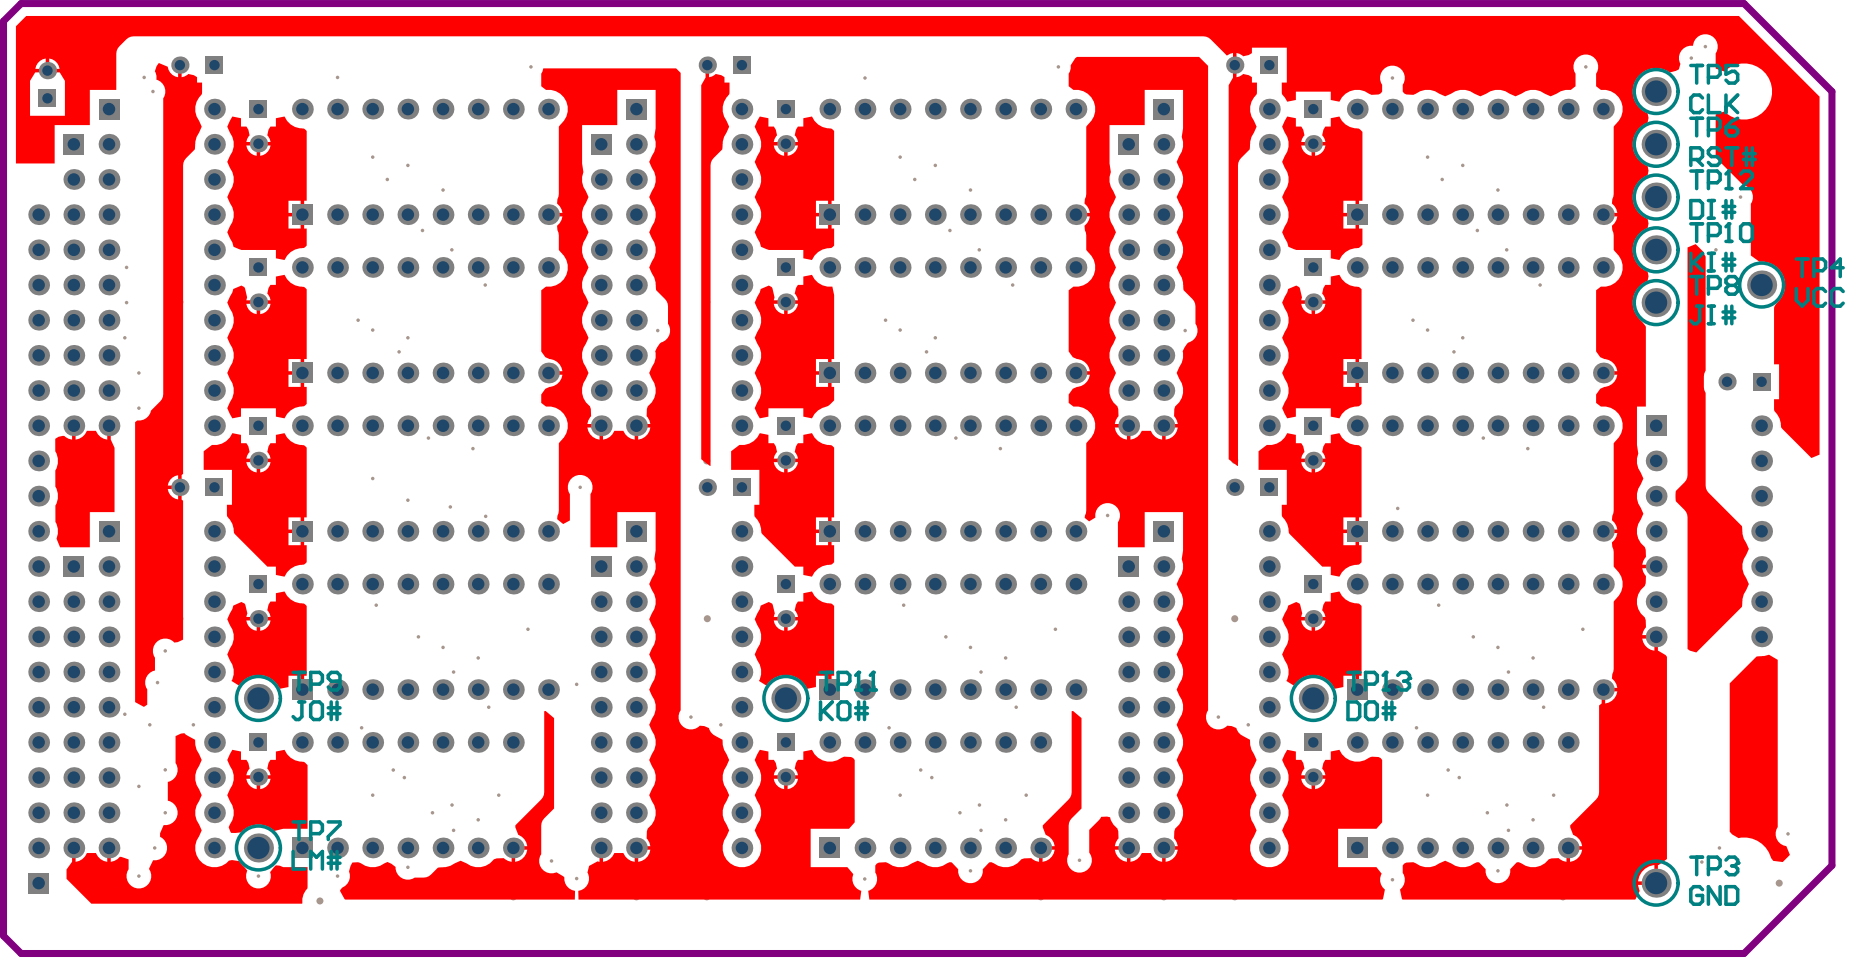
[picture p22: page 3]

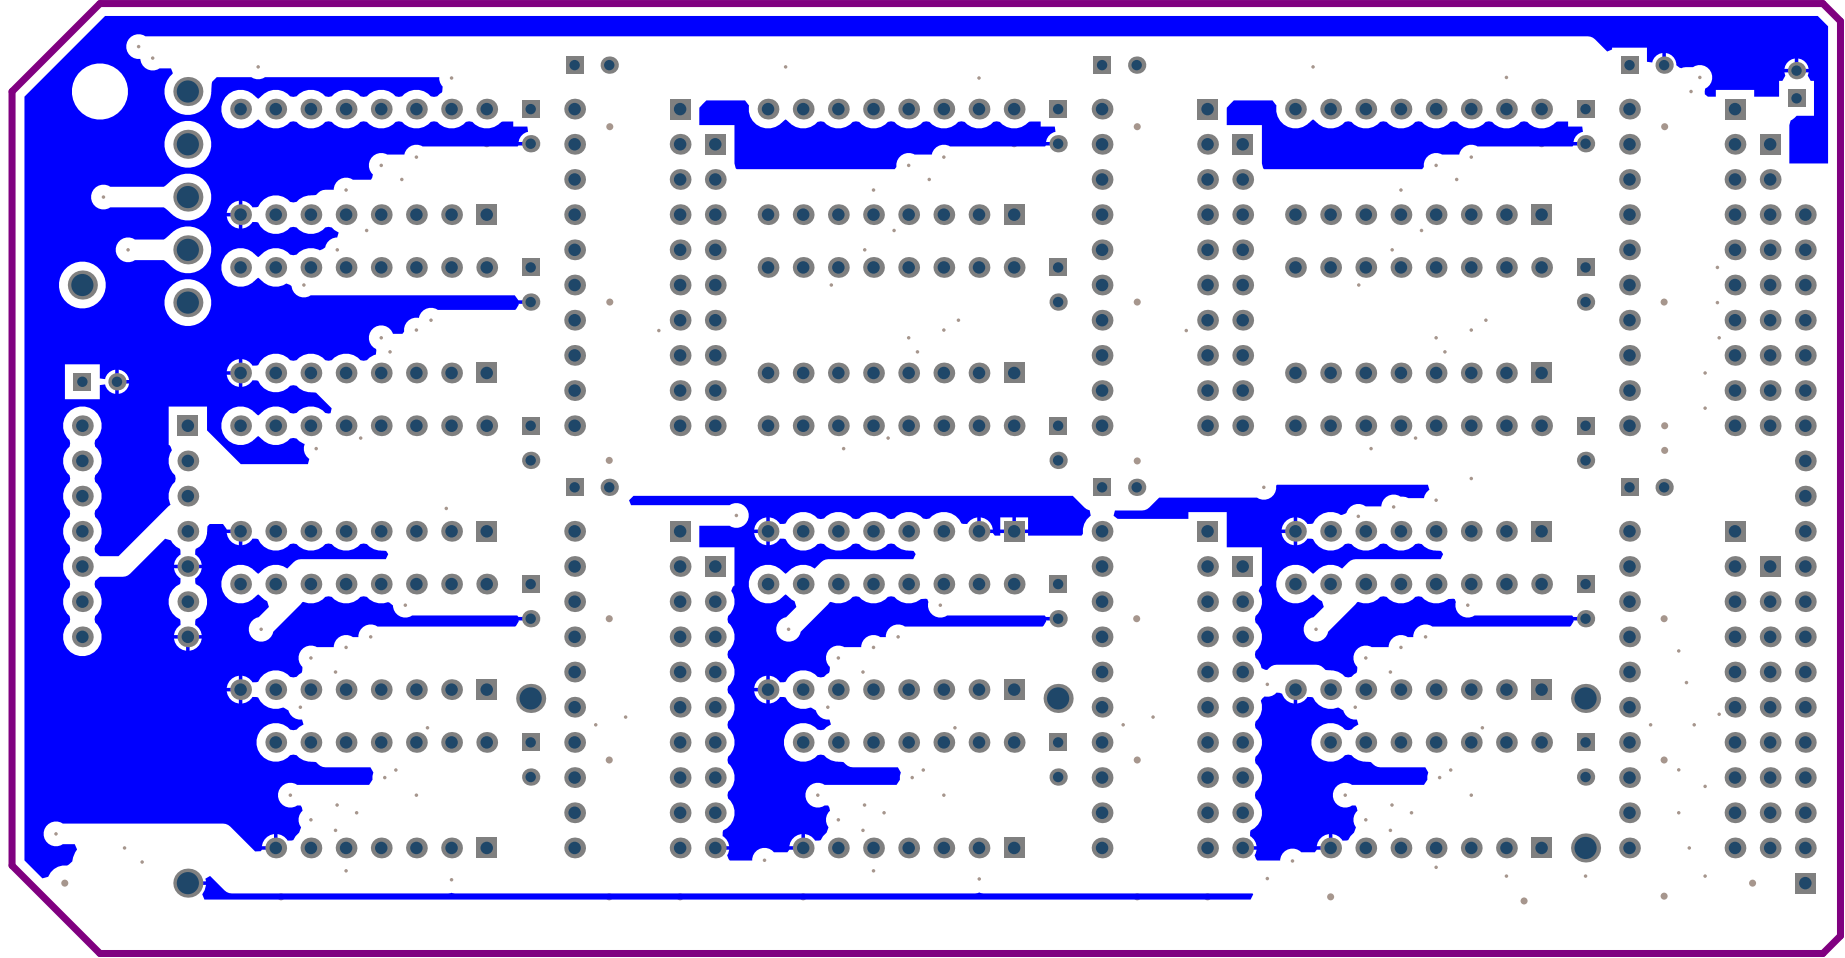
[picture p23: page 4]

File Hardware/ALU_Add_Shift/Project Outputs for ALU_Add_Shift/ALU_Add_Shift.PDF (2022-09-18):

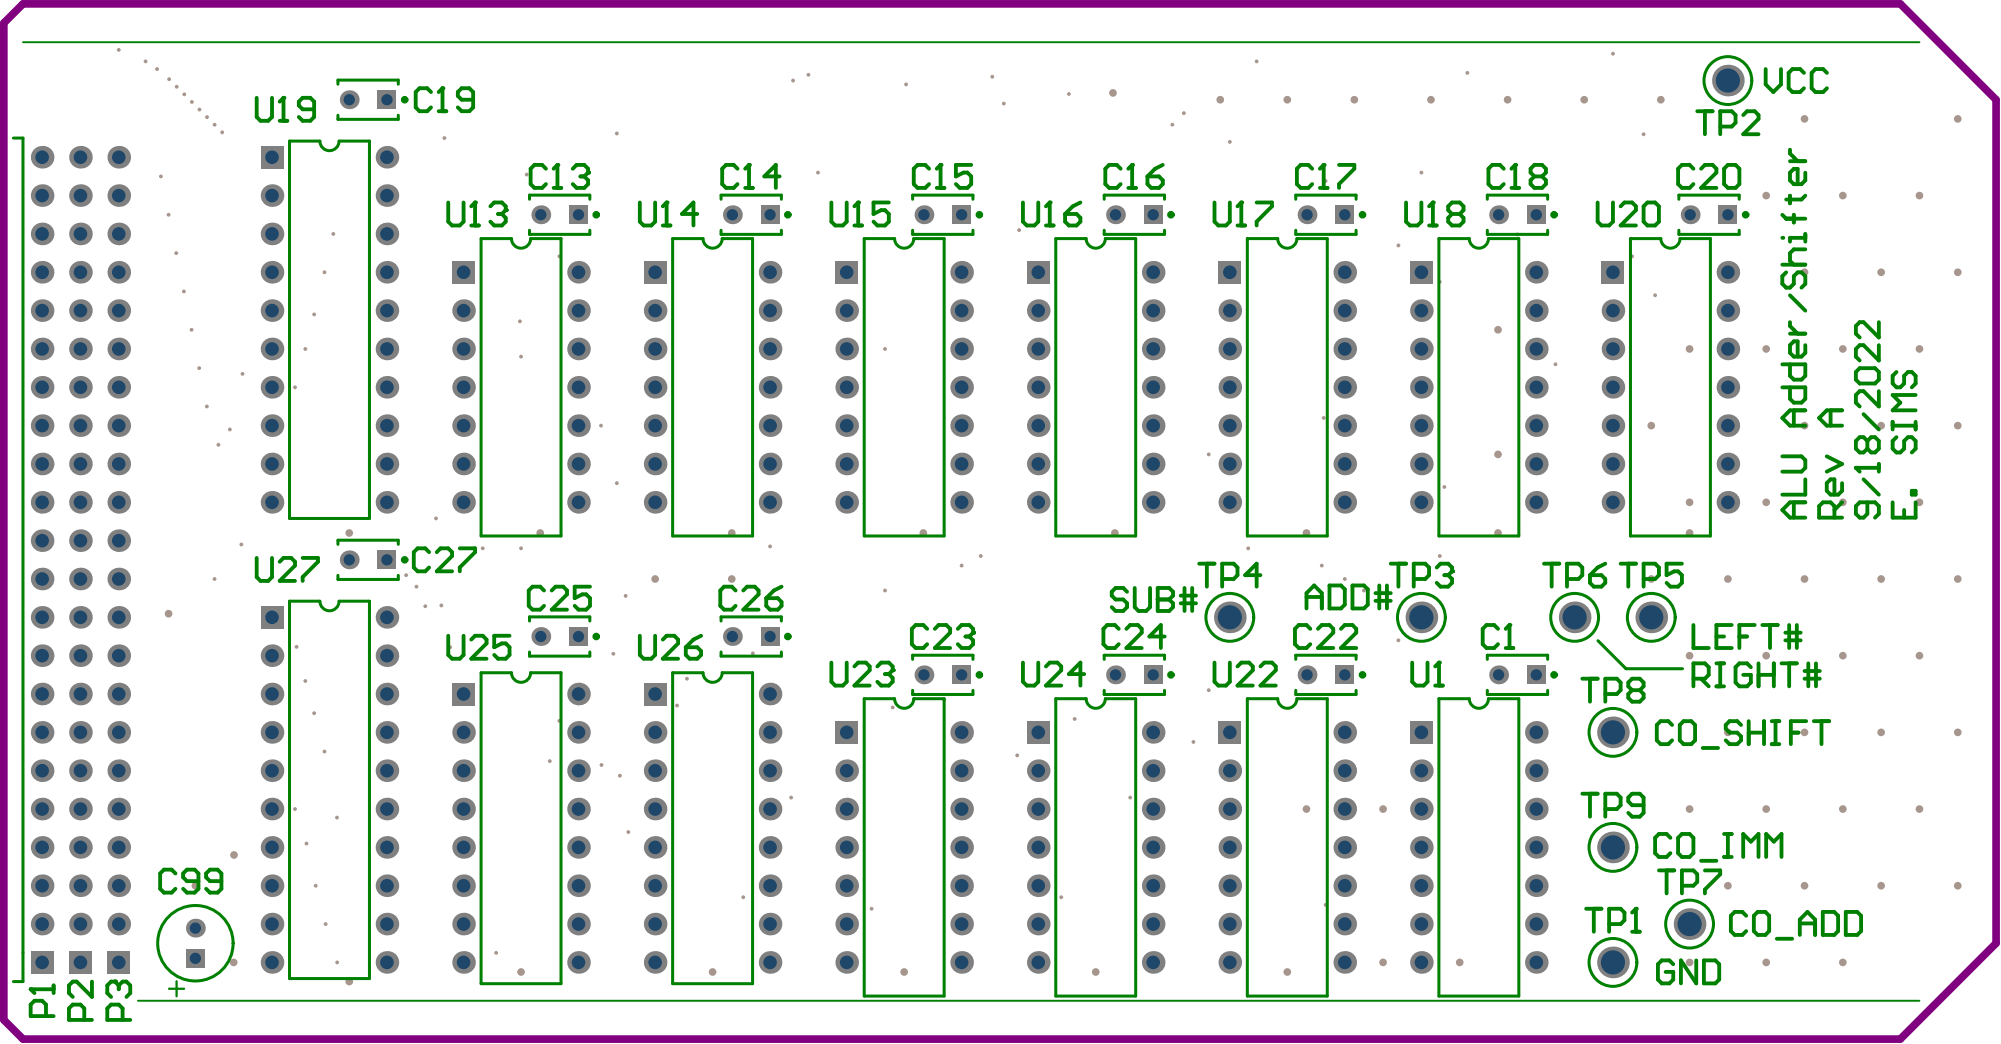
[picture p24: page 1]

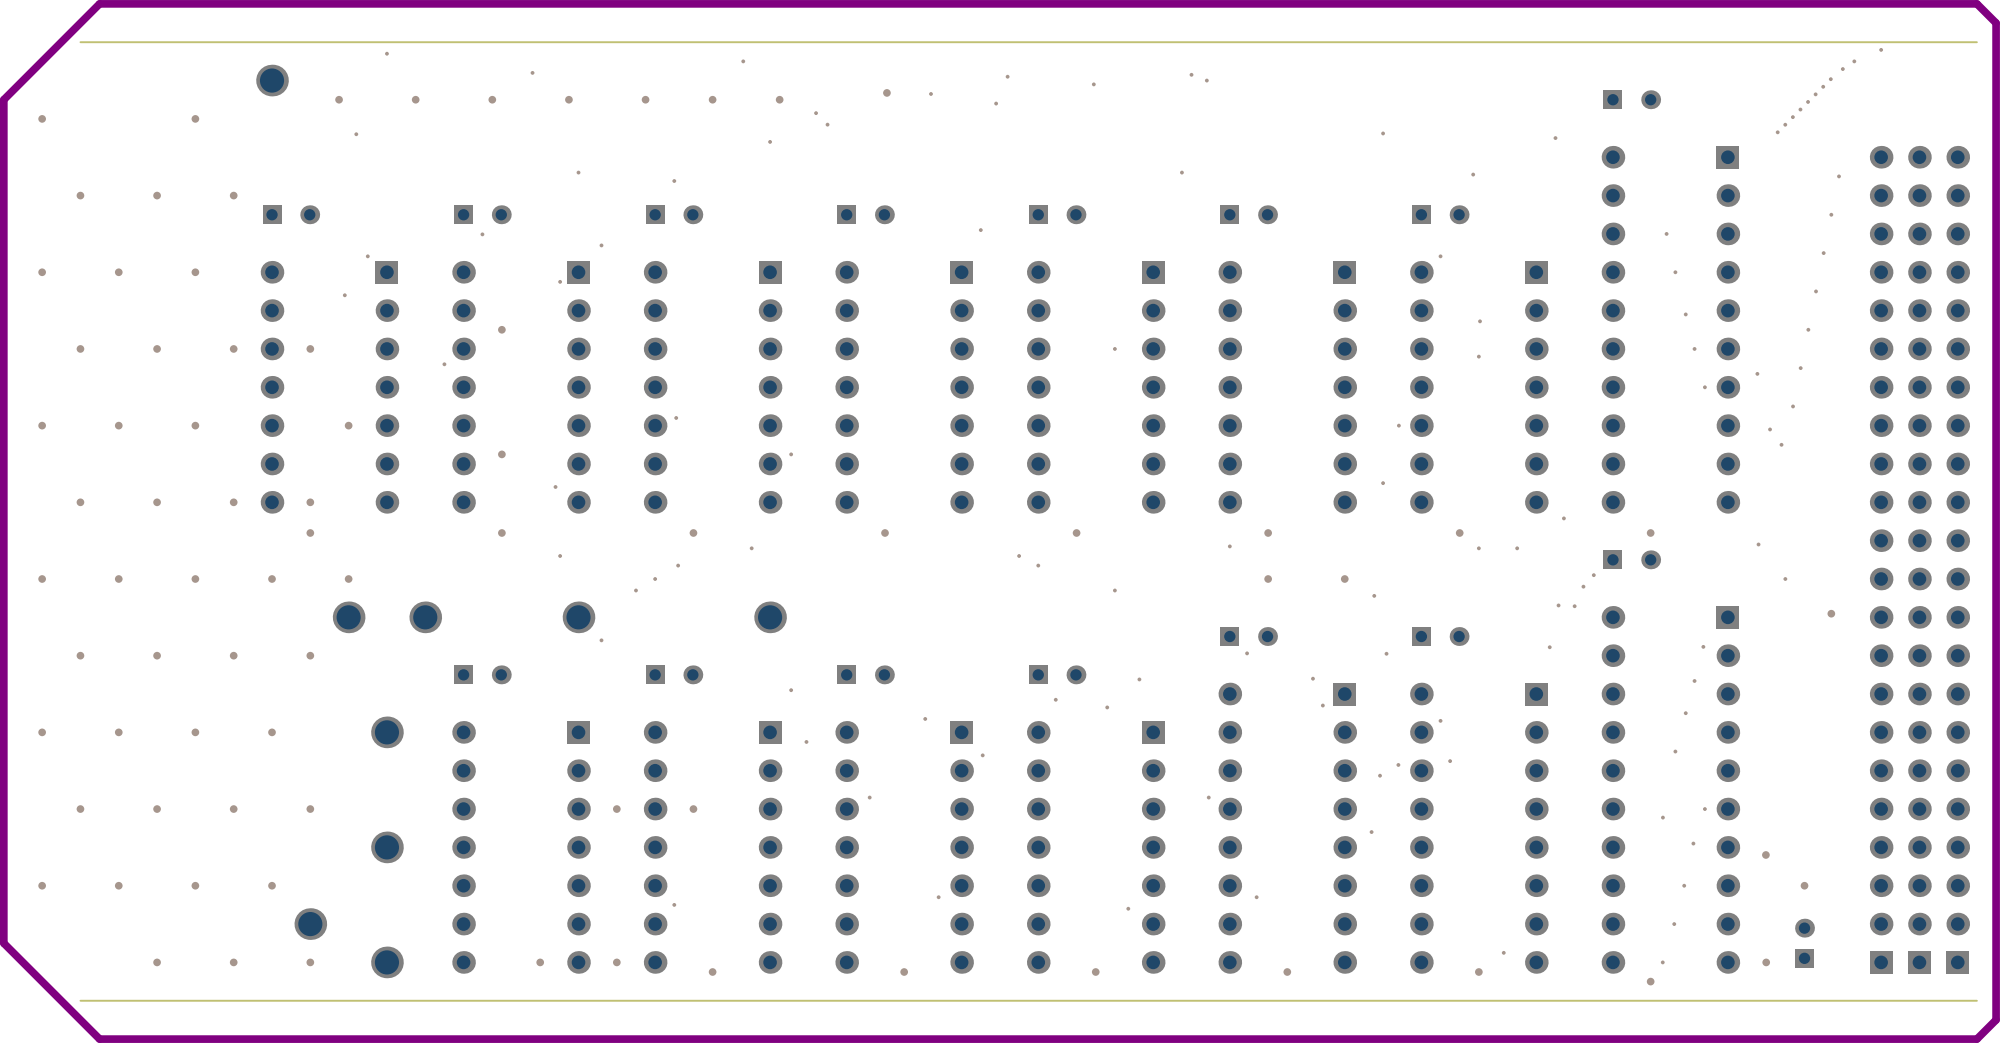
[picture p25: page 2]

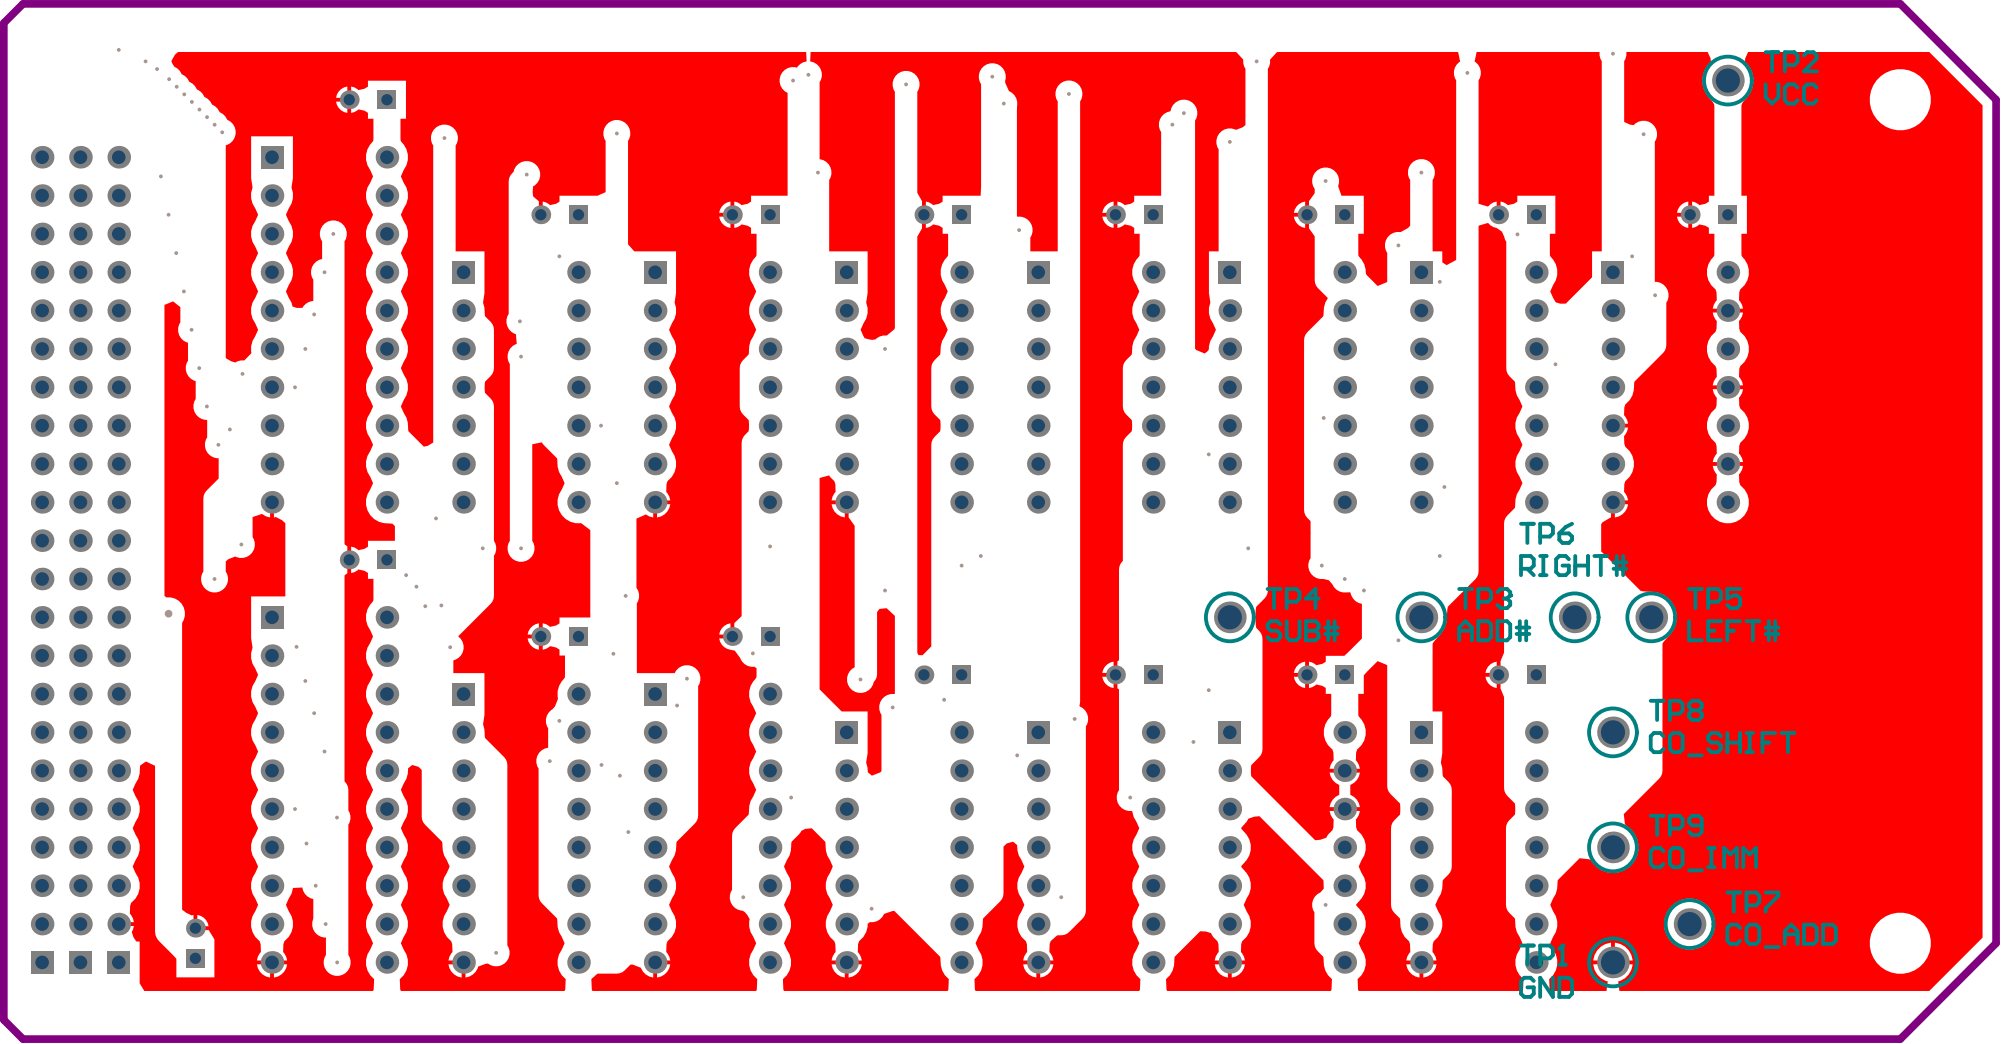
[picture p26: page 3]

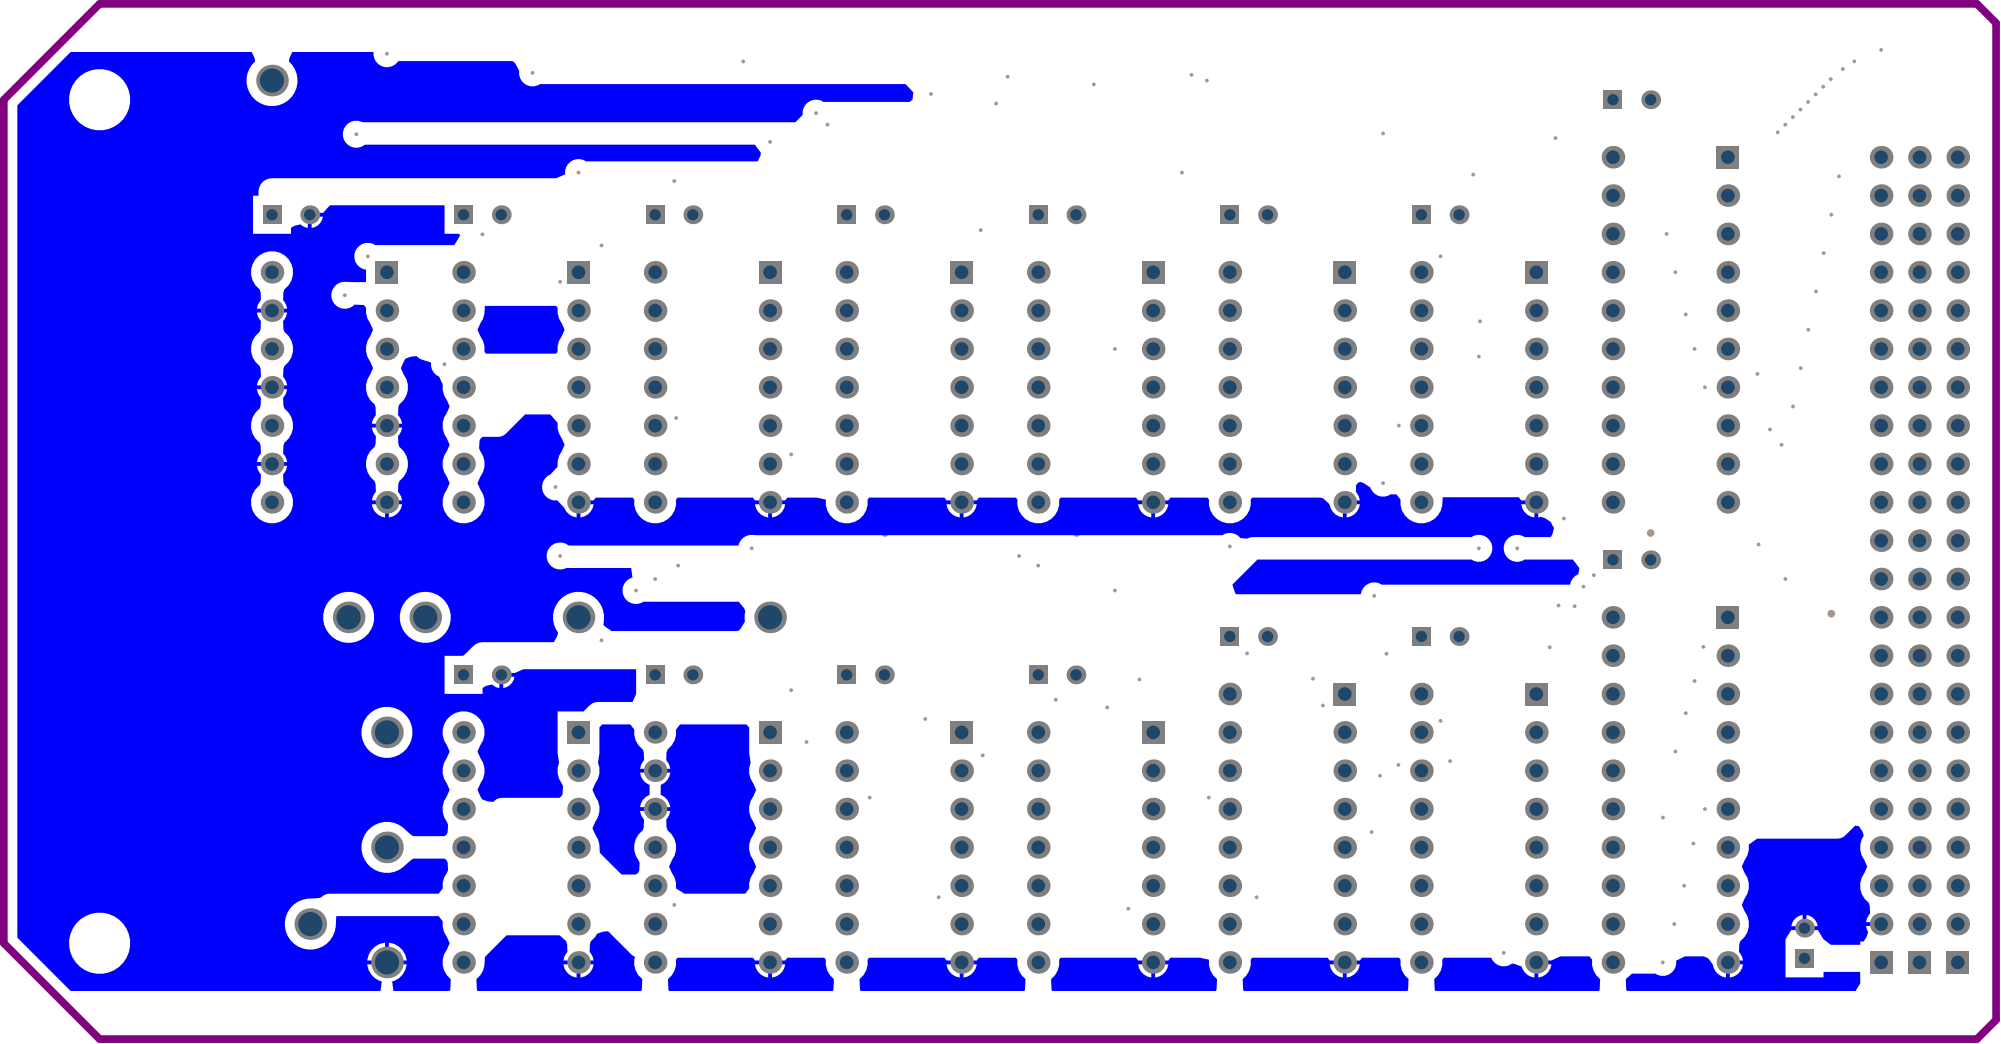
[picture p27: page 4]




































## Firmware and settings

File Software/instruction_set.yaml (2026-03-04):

---
control_signals:
  - OUT:  # 4 bits, 16 options
      - NONE:  # 0
          description: 'none'
      - HT:  # 1
          description: 'Halt'
      - PO:  # 2
          description: 'Program Counter Out'
      - AO:  # 3
          description: 'A Register Out'
      - BO:  # 4
          description: 'B Register Out'
      - MO:  # 5
          description: 'Memory Out'
      - NO:  # 6
          description: 'Stack Pointer Out'
      - SO:  # 7
          description: 'Stack Out'
      - HO:  # 8
          description: 'HL Register Out'
      - JO:  # 9
          description: 'J Scratch Register Out'
      - KO:  # 10
          description: 'K Scratch Register Out'
      - DO:  # 11
          description: 'D Scratch Register Out'
    bits: 4
  - IN:  # 4 bits, 16 options
      - NONE:  # 0
          description: 'none'
      - PI:  # 1
          description: 'Program Counter In'
      - II:  # 2
          description: 'Instruction Register In'
      - XI:  # 3
          description: 'ALU X Register In'
      - YI:  # 4
          description: 'ALU Y Register In'
      - AI:  # 5
          description: 'A Register In'
      - BI:  # 6
          description: 'B Register In'
      - HI:  # 7
          description: 'HL Register In'
      - MA:  # 8
          description: 'Memory Address Register In'
      - MI:  # 9
          description: 'Memory In'
      - NI:  # 10
          description: 'Stack Pointer In'
      - SI:  # 11
          description: 'Stack In'
      - JI:  # 12
          description: 'J Scratch Register In'
      - KI:  # 13
          description: 'K Scratch Register In'
      - DI:  # 14
          description: 'D Scratch Register In'
    bits: 4
  - ALU:  # 4 bits
      - NONE:  # 0
          description: 'none'
      - ADD:  # 1
          description: 'Add'
      - SUB:  # 2
          description: 'Subtract'
      - AND:  # 3
          description: 'Logical AND'
      - OR:   # 4
          description: 'Logical OR'
      - XOR:  # 5
          description: 'Logical XOR'
      - SHL:  # 6
          description: 'Logical Shift Left'
      - SHR:  # 7
          description: 'Logical Shift Right'
      - ONES:  # 8
          description: 'Output 0xFF'
      - ZERO:  # 9
          description: 'Output 0x00'
      - ONE:  # 10
          description: 'Output 0x01'
    bits: 4
  - CE:
      description: 'Program Counter Enable'
      active: low
  - FI:
      description: 'ALU Flag Refresh'
      active: low
  - LM:
      description: 'Bus MSB Byte Select'
      active: low
  - RU:
      description: 'Reset Microcode Counter'
      active: low
  - MC:
      description: 'Memory Address Increment'
      active: low
  - IS:
      description: 'Increment Stack Pointer'
      active: low
  - DS:
      description: 'Decrement Stack Pointer'
      active: low
  - AT:
      description: 'Assert Condition'
      active: low
  - UC20:
      description: 'RFU20'
      active: low
  - UC21:
      description: 'RFU21'
      active: low
  - UC22:
      description: 'RFU22'
      active: low
  - UC23:
      description: 'RFU23'
      active: low

input:
  - ucode_count:  # ucode counter keyword. don't change
      bits: 6
  - instruction:  # instruction keyword. don't change
      bits: 8
  - ZF:
      description: 'Zero Flag'
      active: high
  - CF:
      description: 'Carry Flag'
      active: high
  - NF:
      description: 'Negative Flag'
      active: high
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

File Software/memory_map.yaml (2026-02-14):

---
defaults:
  # Layout options
  unit_size: 0x1000
  unit_height: 0.325
  min_height: 0.675
  max_height: 3
  discontinuity_height: 0.625
  region_width: 1.5

  # Presentation options
  background: "#fff"
  fill: '#C7E3EC'
  outline: '#336DA5'

  # Address labels
  address_format: c
  size_format: si

automatic:
  discontinuities:
    fill: "#fff"
    style: dashed
  addresses:
    side: right
    start: true
    end: false
    size: false
    final_end: true
    end_exclusive: false

layout:
  0x0000:
    size: 0x4000
    label: "ROM"
    labels:
      "er,ic": "16 KiB"
      "el,ib": "TEXT"
    bank: true
    fill: '#D7D3EC'
    location: 1
  0x4000:
    size: 0x8000
    label: "RAM"
    labels:
      "er,ic": "32 KiB"
      "el,ib": "↑\nSTACK\nBSS"
    bank: true
    fill: "#C7F3DC"
    location: 2
  0xC000:
    size: 0x2002
    label: "EXRAM"
    labels:
      "er,ic": "8 KiB x 256\n(2 MiB)"
    location: 3
  0xE002:
    size: 0x0002
    label: "UART"
    location: 5
  0xE004:
    size: 0x0002
    label: "MOT"
    location: 6
  0xE006:
    size: 0x0002
    label: "RA8876"
    location: 8
  0xE010:
    size: 0x0002
    label: "SDCARD"
    location: 4
  0xE400:
    size: 0x400
    label: "ETH"
    location: 7

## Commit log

2021-09-12 first pass
    [ALU.SchDoc, ALU_AND.SchDoc, ALU_Adder.SchDoc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]
2021-09-12 ref des
    [ALU.SchDoc, ALU_AND.SchDoc, ALU_Adder.SchDoc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]
2021-09-12 working on multibyte load
    [ALU.SchDoc, Accumulator_Register.SchDoc, Memory_Address_Register.SchDoc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]
2021-09-12 memory address decode and LSB/MSB registers
    [Accumulator_Register.SchDoc, Memory_Address_Register.SchDoc, Memory_EEPROM.SchDoc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]
2021-09-12 uCode work
    [ALU.SchDoc, ALU_Adder.SchDoc, ALU_Shifter.SchDoc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]
2021-09-12 breaking out to individual boards
    [ALU.SchDoc, ALU_ADDER.PrjPcb, ALU_AND.PcbDoc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]
2021-09-13 added 3d models and libraries... sorry the repo is so big now... need to minimize later
    [ALU.SchDoc, ALU_AND.PcbDoc, ALU_AND.SchDoc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]
2021-09-13 what am i doing with my life
    [93655A013_Male-Female Threaded Hex Standoff.STEP, 93655A013_Male-Female Threaded Hex Standoff.ipt, ALU.0004.iam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]
2021-09-22 added encoder inputs
    [Encoder.SchDoc, Memory_SRAM.SchDoc, Microcode.SchDoc]
2021-10-03 working on encoder and motor stuff
    [8B.0009.iam, 8B.iam, ALU.0004.iam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]
2021-10-10 rearragnged regs, increase addr bus, consolidate, add gitignore
    [ALU Connector.SchDoc, Backplane.PcbDoc, Backplane.PrjPcb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]
2021-10-16 moving around control signals
    [Microcode.SchDoc]
2021-10-16 simple simulator
    [Instruction Set.ods]
2021-10-16 supporting JMP
    [Instruction Set.ods]
2021-10-17 address decoding working, jumps working, flags working, fibanacci progam working
    [Instruction Set.ods]
2021-10-17 asemblr and call/ret instructions
    [Instruction Set.ods]
2021-10-17 multiply and divide
    [Instruction Set.ods]
2021-10-17 added left and right shift, improved prime caclutor for fun
    [Instruction Set.ods]
2021-10-20 itoa work
    [ALU.SchDoc, Control Logic.PcbDoc, Instruction Set.ods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]
2021-10-23 added test instucitons and itoa is now working
    [Instruction Set.ods]
2021-12-05 sim work
    [Backplane.PrjPcb, Control Logic.PcbDoc, Scratch.SchDoc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]
2021-12-06 power path
    [Debugger.SchDoc, PCB1.PcbDoc, Power_Clock.PrjPcb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]
2021-12-13 before refactoring implmentianot of ctrl sim
    [Instruction Set.ods]
2021-12-13 yaml is boss now
    [Instruction Set.ods]
2021-12-18 more asm sim work
    [Instruction Set.ods]
2021-12-19 added some word operations
    [Instruction Set.ods]
2021-12-20 gcc-esque function calls work!
    [Instruction Set.ods]
2022-01-02 stack accesss macros
    [Instruction Set.ods]
2022-01-03 i dunno
    [Microcode.SchDoc, Register.PcbDoc, Register.SchDoc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]
2022-01-16 work on scratch reg and math functions
    [Register.PcbDoc, Register_16B.SchDoc, Scratch.PcbDoc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]
2022-06-27 idk. so much shit
    [ALU Connector.SchDoc, Backplane.PrjPcb, Backplane.SchDoc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]
2022-07-01 more backplane work
    [ALU Connector.SchDoc, Backplane.PcbDoc, Backplane.PrjPcb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]
2022-07-01 more backplane work, including logic port layout
    [Backplane.PcbDoc, Backplane.SchDoc, Control Logic.PrjPcb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]
2022-07-02 moved to SMD probe compensation
    [Control Logic.PrjPcb, Logic Port.SchDoc, Top.SchDoc]
2022-07-02 more work on CTRL
    [Decode.SchDoc, Microcode.SchDoc, Top.SchDoc]
2022-07-03 refactored net names from overbar to pound for inverted logic
    [Backplane.PcbDoc, Backplane.SchDoc, Control Logic.SchDoc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]
2022-07-03 backplane routing and mechanicals
    [0603.ipt, 091X540X323_100081373MOD000B_RGB8421504.ipt, 19248534240.0001.iam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]
2022-07-05 more backplane work, fixed memory pinouts
    [ALU Connector.SchDoc, ALU_Ctrl.SchDoc, Backplane.PcbDoc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]
2022-07-07 testpoints and more backplane stuff
    [Assembly Testpoint Report for Backplane.csv, Backplane.PcbDoc, Backplane.PrjPcb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]
2022-07-10 MAR_SAR work
    [ALU_Ctrl.SchDoc, Address Mux.SchDoc, Block Diagram.SchDoc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]
2022-07-11 alu migrated from old design
    [ALU.SchDoc, ALU_ADDER.SchDoc, ALU_AND.SchDoc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]
2022-07-16 routed alu adder
    [ALU_ADDER.SchDoc, ALU_Add_Shift.PcbDoc, ALU_Add_Shift.PrjPcb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]
2022-07-16 finished adder and alu logic. started regs
    [ALU_AND.SchDoc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]
2022-07-18 routed ALU ctrl
    [ALU Connector.SchDoc, ALU_Add_Shift.PcbDoc, ALU_Add_Shift.PrjPcb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]
2022-07-23 routing scratch regs
    [Scratch.PcbDoc, Scratch.PrjPcb, Scratch_Register_16B.SchDoc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]
2022-07-25 lots of routing and mech work
    [19248534240.0001.iam, 19248534240.iam, 19248548000.0001.iam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]
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2022-08-28 changed card pitch to 800mils, started clk_power proto
    [ALU_Ctrl.PrjPcb, Backplane.PcbDoc, Backplane.PrjPcb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]
2022-09-18 some board ready to order
    [ALU Connector.SchDoc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]
2023-08-13 oops. looks like i never commited. idk what changed
    [ALU_Add_Shift.PrjPcb, ALU_Ctrl.PrjPcb, ALU_Logic.PrjPcb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]
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2023-09-30 reorg 2 - SW
    [Instruction Set.ods]
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2023-10-24 half way thru dijkstras algo
    [Instruction Set.ods]
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2024-10-07 change stack growth order to fix endianess. need to change parameter order of all functions
    [instruction_set.yaml]
2024-11-04 flash based address decoder
    [Decode.SchDoc, Memory Address Decoder.PcbDoc, Memory Address Decoder.PrjPcb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]
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2026-02-06 adding card cage files
    [ALU_Ctrl.PcbDoc, Assembly.FCStd, Backplane.FCStd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]
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2026-02-13 sd card emulations working for reads. need to fix fs driver now
    [cli.asm]
2026-02-14 working sdcard v1 emulation!
    [Assembly.FCStd, card_cage.FCStd, mid_cage.FCStd]
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2026-02-16 woah! i can connet to sockets and perform an http get! stil need to fix RX fifo, since it think it is breaking on word boundries
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2026-02-22 cpu now handles assert instructions
    [Memory_EEPROM.PcbDoc]
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2026-02-23 starting SD card design
    [Memory_SD_Card.PcbDoc, Memory_SD_Card.PrjPcb, Memory_SD_Card.SchDoc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]
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
